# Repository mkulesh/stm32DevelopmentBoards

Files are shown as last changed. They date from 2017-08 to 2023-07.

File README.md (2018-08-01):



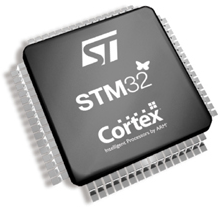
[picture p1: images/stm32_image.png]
#  "Development boards and software templates for STM32 MCU"

This repository contains schematic of development boards, PCB, and C++ source code templates that can be helpful for development using STM32 micro-controllers. It provides small, universal, and breadboards-friendly adapter and development board for wide range of STM32 controllers.  There are three sets:

## STM32-Pi Board

The first board is a two-layers STM32F4 board, which have a form-factor of Raspberry Pi B+ that allows us to use any case available for this single-board computer:

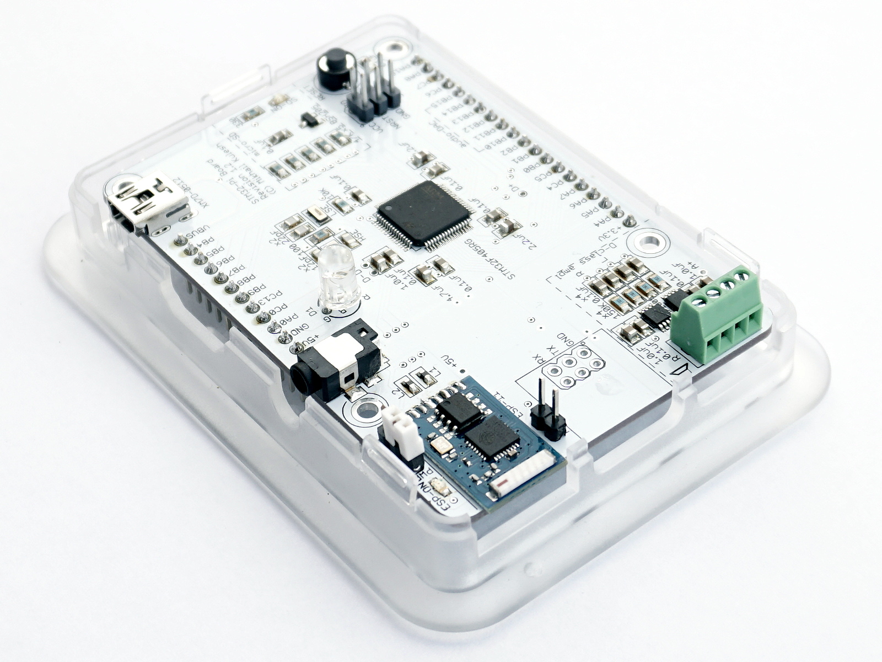
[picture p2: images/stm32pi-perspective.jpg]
Case view


If you like to test this board, you can order it [on DirtyPCBs.com](http://dirtypcbs.com/store/designer/details/9348/6105/stm32-pi-board-v1-3-zip)

### Specification
* It is based on high-performance ARM®Cortex®-M4 32-bit RISC micro-controller [STM32F405RG](http://www.st.com/en/microcontrollers/stm32f405rg.html)
* SMD HSE and LSE crystals
* Micro SD Card Connector
* Mini USB Type B Connector with USB EMI filtering and ESD protection. This connector can be used for data transfer and powering
* A separate +5V DC connector (1 mm X 3.2 mm) instead of Raspberry Pi audio jack
* 6-pin SWD connector used to program the MCU
* [ESP8266](https://en.wikipedia.org/wiki/ESP8266) WiFi Module ESP-11 instead of Raspberry Pi network connector
* 5-pin connector used to flash and program the ESP-11 module
* Breadboard-compatible 1x20-pin and 1x10-pin headers connected to free MCU pins
* Reset button
* One RGB LED
* Low power audio DAC with PLL UDA1334ATS
* 2x class-D mono audio power amplifier IS31AP2005 (2 x 2.95W) 
* 4 pads for audio output instead of Raspberry Pi USB connector
* SMD size for passive components is 0805

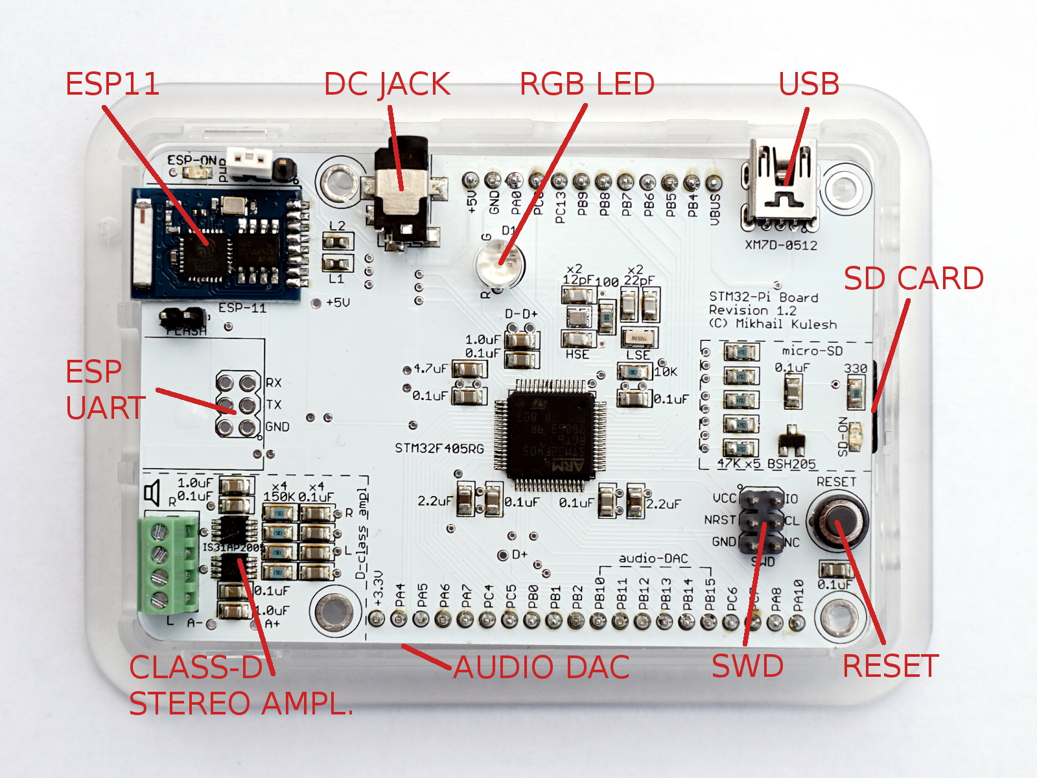
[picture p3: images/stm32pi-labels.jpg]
Top view


### Documentation
* [Отладочная плата STM32F4 в форм-факторе Raspberry Pi (In Russian)](https://habr.com/post/413101)
* [Schematic](https://docs.google.com/viewer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) 
* [Dimensions](https://docs.google.com/viewer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) 
* [Top layer](https://docs.google.com/viewer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)
* [Bottom layer](https://docs.google.com/viewer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) 
* [Bill of materials](http://htmlpreview.github.io/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)
* The C++ example in the directory [src/PI405RG](https://github.com/mkulesh/stm32DevelopmentBoards/tree/master/src/PI405RG) demonstrates how to use RTC, SD Card with FatFS, and ESP-11 module.

## Universal STM32 Boards:

These developments boards are two-side breadboard adapters for LQFP32/48/64 IC's, equipment with adaptable power supply circuit, HSE and LSE crystal circuit, reset button, and a **custom** 10-pin JTAG connector. SMD size for passive components is 0805. 

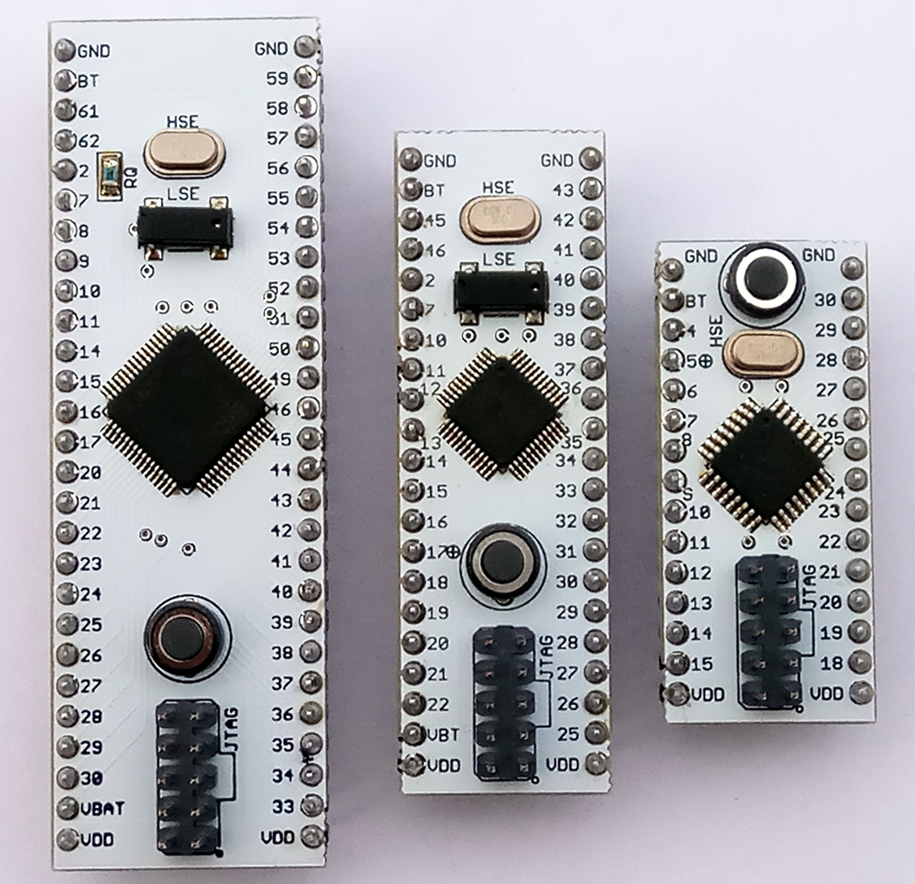
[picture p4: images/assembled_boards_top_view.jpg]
Assembled boards


The adapter between 20-pin JTAG and this custom connector is also included in the set:

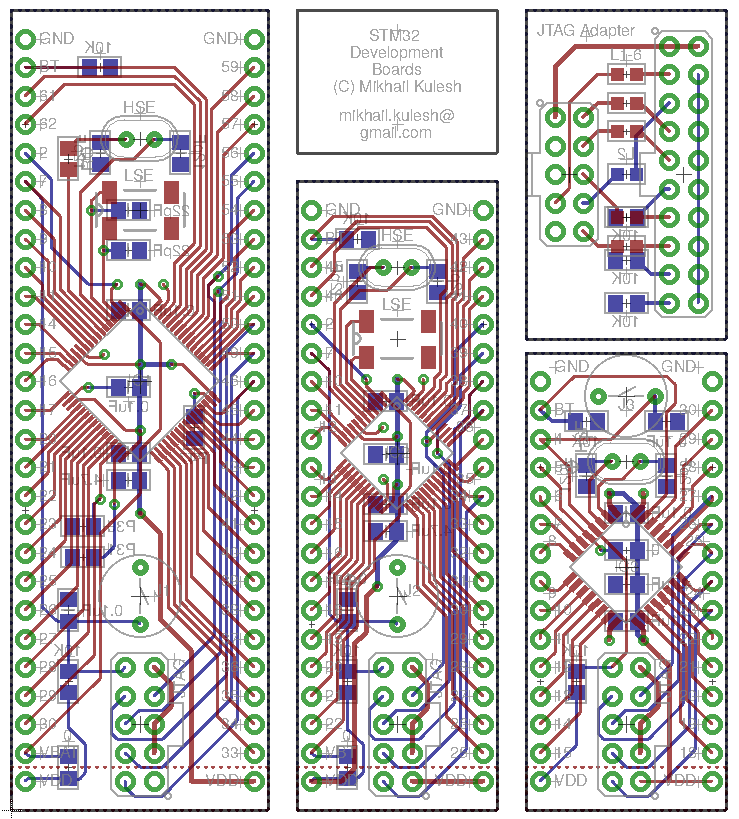
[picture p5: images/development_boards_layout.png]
Development boards layout


You can order these boards [on DirtyPCBs.com](http://dirtypcbs.com/store/designer/details/9348/5771/stm32-development-boards)

## LQFP-Breadboard Adapters:

These boards are just one-side breadboard adapters for LQFP32/48/64 IC's:

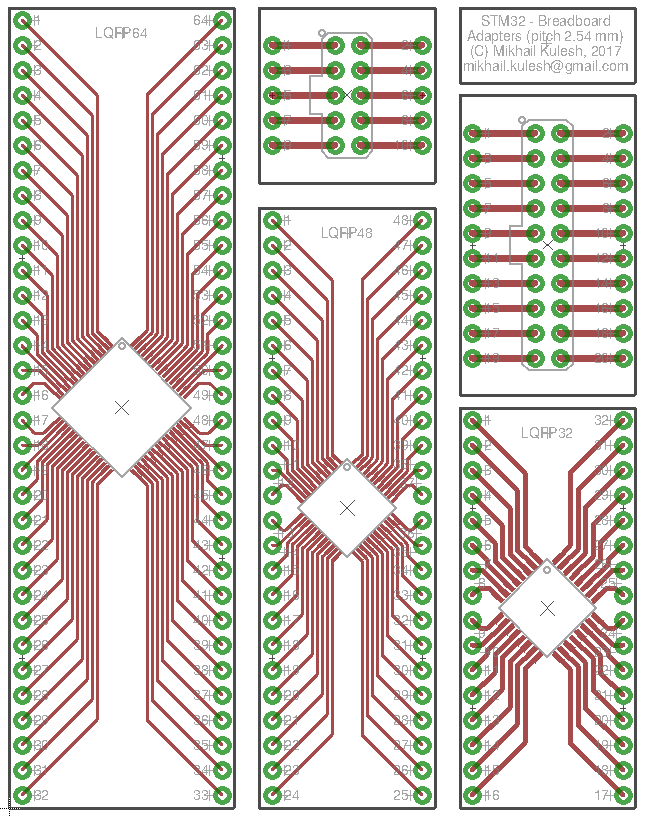
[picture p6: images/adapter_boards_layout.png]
Adapter boards layout


You can order these boards [on DirtyPCBs.com](http://dirtypcbs.com/store/designer/details/9348/5770/lqfp-adapters-zip)

## Repository Content:

* The directory **pcb** contains schematic and board layout developed in [Eagle CAD](https://www.autodesk.com/products/eagle/free-download)
* In the directory **images**, you can find some photos of assembled boards
* The directory **src** contains test examples developed in [System Workbench for STM32](http://www.st.com/en/development-tools/sw4stm32.html). These test programs are based on HAL library and an object-oriented abstraction layer called *StmPlusPlus*. Currently, following chips are tested: STM32F303K8Tx, STM32F303RBTx, STM32F373CBTx, STM32F373CCTx, STM32F410RBTx,  STM32F405RGTx

## Reviews and Publications:
* [Discussion on www.mikrocontroller.net (In German)](https://www.mikrocontroller.net/topic/433910)
* [Нестандартный способ подружиться с STM32: не Ардуино и не Discovery (In Russian)](https://habr.com/post/406313)

## License
This software is published under the *GNU General Public License, Version 3*

Copyright (C) 2014-2017 Mikhail Kulesh

This program is free software: you can redistribute it and/or modify it under the terms of the GNU General Public License as published by the Free Software Foundation, either version 3 of the License, or (at your option) any later version.

This program is distributed in the hope that it will be useful, but WITHOUT ANY WARRANTY; without even the implied warranty of MERCHANTABILITY or FITNESS FOR A PARTICULAR PURPOSE.  See the GNU General Public License for more details. You should have received a copy of the GNU General Public License along with this program.

If not, see [www.gnu.org/licenses](http://www.gnu.org/licenses).

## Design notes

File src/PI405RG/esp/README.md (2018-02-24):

# How to setup ESP-11 and flash firmware (on Linux host)

* Ensure that the [esptool](https://github.com/themadinventor/esptool) is istalled on the host PC

* Select ditectory *stm32DevelopmentBoards/src/PI405RG/esp*

* Ensure that power for STM32-Pi board is OFF

* Connect pins **1** and **2** on the **PWR** switch. Connect an USB-UART adapter to ESP pins GND/TX/RX as shown on the figure below:

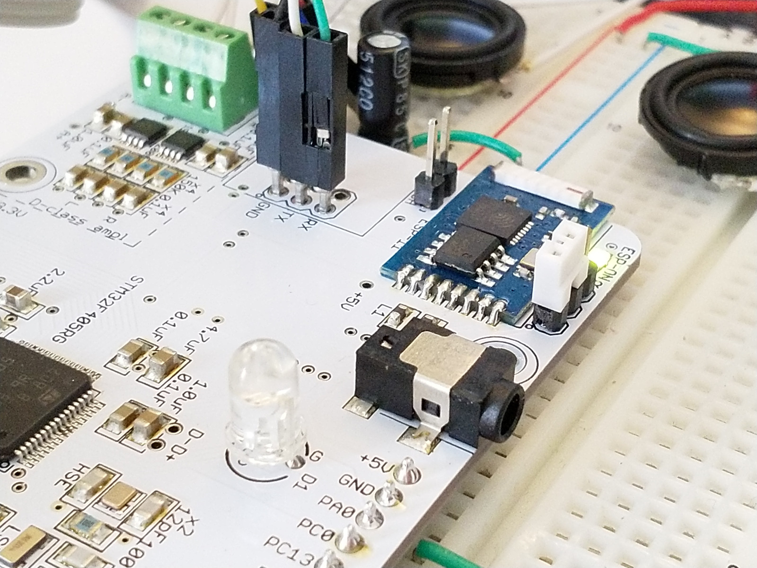
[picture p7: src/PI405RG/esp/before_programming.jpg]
Before programming


* On the host, ensure whether the USB-UART adapter is alive:
```
[stm32DevelopmentBoards/src/PI405RG/esp]# lsusb
Bus 001 Device 035: ID 0403:6001 Future Technology Devices International, Ltd FT232 Serial (UART) IC
```

* Run any terminal and connect to the ESP using following settings: baudrate **9600**, data bits **8**, parity **none**, stop bits **1**. For example, you can run CoolTerm, open there a file *CoolTermConfig.stc* and change the baudrate to **9600**.

* Switch power to ON

* In the terminal, you will see following logging:
```
[Vendor:www.ai-thinker.com Version:0.9.2.4]
ready
```

* Switch power to OFF, disconnect terminal, connect the pins **FLASH** as shown on the figure below and switch power to ON again.

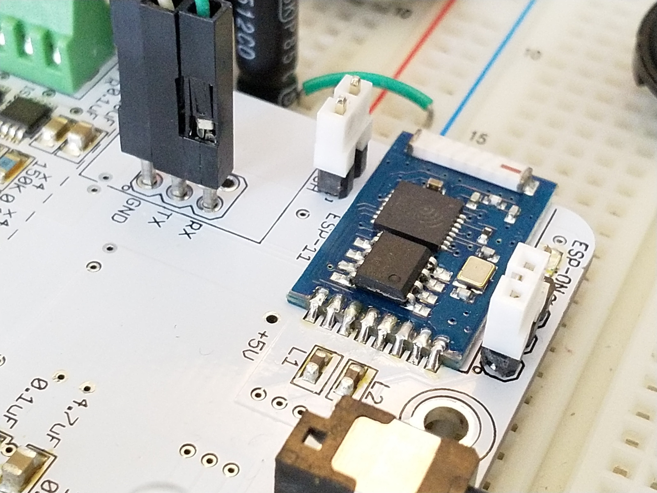
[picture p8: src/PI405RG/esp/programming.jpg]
Programming


* Adapt and run the script *flash-firmware.sh*: 
```
[stm32DevelopmentBoards/src/PI405RG/esp]# ./flash-firmware.sh 
Make sure that GPIO0 is connected to ground
esptool.py v2.2-dev
Connecting....
Detecting chip type... ESP8266
Chip is ESP8266EX
Uploading stub...
Running stub...
Stub running...
Configuring flash size...
Auto-detected Flash size: 512KB
Compressed 520192 bytes to 179836...
Wrote 520192 bytes (179836 compressed) at 0x00000000 in 16.1 seconds (effective 258.5 kbit/s)...
Hash of data verified.
Leaving...
Hard resetting...
```

* Switch power to OFF, disconnect **FLASH** pins

* In the terminal, change the baudrate to **115200**, connect to ESP and switch power to ON again. 
After ESP logs *ready*, check the actial firmware version using command *AT+GMR*:
```
AT+GMR
AT version:0.23.0.0(Apr 24 2015 21:11:01)
SDK version:1.0.1
compile time:May  9 2015 16:00:00
OK
``` 
* Connect pins **2** and **3** on the **PWR** switch. Now ESP can be accessed from MCU using USART2.

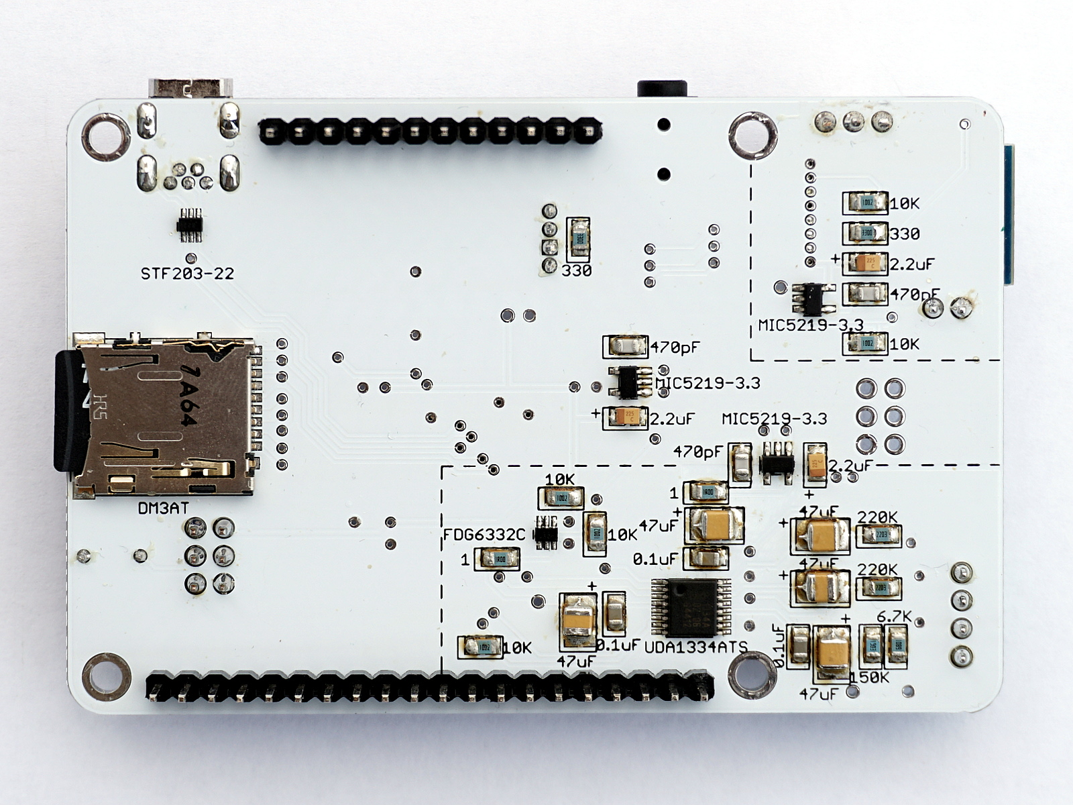
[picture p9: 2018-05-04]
images/stm32pi-bottom.jpg

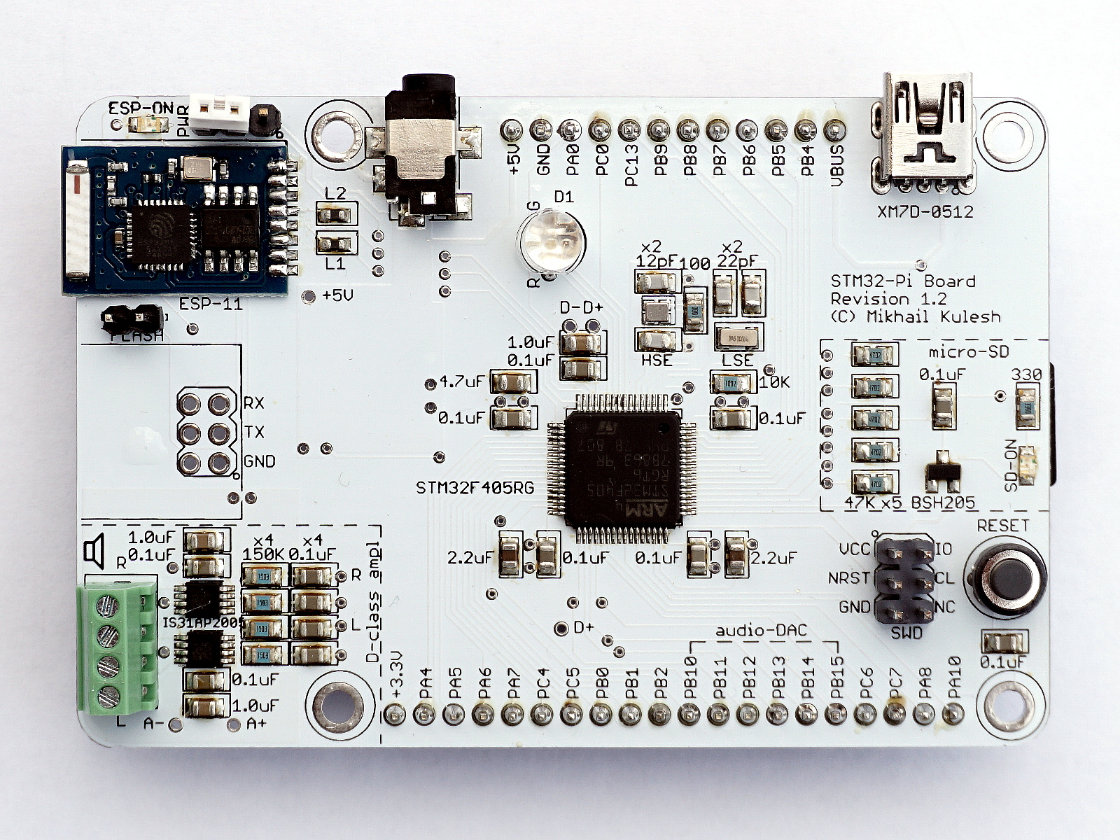
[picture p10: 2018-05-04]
images/stm32pi-top.jpg

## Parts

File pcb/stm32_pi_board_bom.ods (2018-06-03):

Qty | Value | Device | Description | MOUSER | PRICE
1 | BSH205 | BSH205G2R | P-channel enhancement mode MOSFET (-2.3A) | 771-BSH205G2R | 0,252 | 0,252
1 | BUTTON-FSM14JRT | BUTTON-FSM14JRT | TE Connectivity / Alcoswitch Round Switch | 506-1571010-1 | 0,23 | 0,23
16 | 0.1uF | C-US0805 | SMD Multilayer Ceramic Capacitor | 80-C0805C104J5RAUTO | 0,08 | 1,28
3 | 1.0uF | C-US0805 | SMD Multilayer Ceramic Capacitor | 80-C0805C104J5RAUTO | 0,1 | 0,3
2 | 12pF | C-US0805 | SMD Multilayer Ceramic Capacitor | 80-C0805C104J5RAUTO | 0,08 | 0,16
2 | 2.2uF | C-US0805 | SMD Multilayer Ceramic Capacitor | 80-C0805C104J5RAUTO | 0,1 | 0,2
2 | 22pF | C-US0805 | SMD Multilayer Ceramic Capacitor | 80-C0805C104J5RAUTO | 0,08 | 0,16
1 | 4.7uF | C-US0805 | SMD Multilayer Ceramic Capacitor | 80-C0805C104J5RAUTO | 0,1 | 0,1
3 | 470pF | C-US0805 | SMD Multilayer Ceramic Capacitor | 80-C0805C104J5RAUTO | 0,08 | 0,24
3 | 2.2uF | CPOL-US0805 | SMT Tantalum Capacitor | 581-TAJR225K016RNJ | 0,268 | 0,804
5 | 47uF | CPOL-US1311 | SMT Tantalum Capacitor | 581-F951C476KBAAQ2 | 1,34 | 6,7
1 | PJ-043-SMT | DC-POWER-JACK2 | DC Power Connector 1 mm X 3.2 mm | 490-PJ-043-SMT-TR | 0,787 | 0,787
1 | ESP-11 | ESP-11 | ESP8266 WiFi Module ESP-11 |  | 2 | 2
2 | IS31AP2005 | IS31AP2005 | Class-D mono audio power amplifier (2.95W) | 870-31AP2005SLS2TR | 0,574 | 1,148
2 | 420 Ohms | L-USL0603 | SMD Ferrite Bead | 81-BLM11B421S | 0,049 | 0,098
2 | R971 | LEDCHIP-LED0805 | LED | 604-APT2012CGCK | 0,139 | 0,278
2 | 75867-331LF | MA03-2 | Headers & Wire Housing, 2 Row, 6 Position | 649-75867-331LF | 0,623 | 1,246
2 | 68000-420HLF | MA20-1NO-PL | Headers & Wire Housing, 1 Row, 20 Position | 649-68000-420HLF | 0,656 | 1,312
3 | MIC5219-3.3 | MIC5219XX | 500mA-Peak Output LDO Regulator | 998-MIC5219-3.3YM5TR | 0,803 | 2,409
1 | DM3AT | MICRO-SD-DM3AT | DM3 Series microSD Card Connectors | 798-DM3ATSFPEJM511 | 1,95 | 1,95
1 | XM7D-0512 | MINI-USB-5-DPI | Mini USB Type B Connector | 653-XM7D-0512 | 1,56 | 1,56
1 | FDG6332C | N-P-MOS | The N & P-Channel MOSFET | 512-FDG6332C_F085 | 0,262 | 0,262
1 | 16MHz | Q-HSEFA-128 | HSE SMD Crystal | 732-FA12816F20X-AJ0 | 0,533 | 0,533
1 | 32.7680kHz | Q-LSECM7V-T1A | 32.768 kHz SMD Crystal | 428-201562-MG01 | 0,418 | 0,418
2 | 1 | R-US0805 | SMD Resistor | 660-RK73H2ATTDD1R00F | 0,02 | 0,04
1 | 100 | R-US0805 | SMD Resistor | 660-RK73H2ATTDD1R00F | 0,02 | 0,02
3 | 330 | R-US0805 | SMD Resistor | 660-RK73H2ATTDD1R00F | 0,02 | 0,06
6 | 10K | R-US0805 | SMD Resistor | 660-RK73H2ATTDD1R00F | 0,02 | 0,12
5 | 150K | R-US0805 | SMD Resistor | 660-RK73H2ATTDD1R00F | 0,02 | 0,1
2 | 220K | R-US0805 | SMD Resistor | 660-RK73H2ATTDD1R00F | 0,02 | 0,04
5 | 47K | R-US0805 | SMD Resistor | 660-RK73H2ATTDD1R00F | 0,02 | 0,1
1 | 6.7K | R-US0805 | SMD Resistor | 660-RK73H2ATTDD1R00F | 0,02 | 0,02
1 | WP154A4SUREQBFZGC | RGB-LED-5MM | T-1 3/4 (5mm) full color LED lamp | 604-WP154A4SUREQBFZG | 1,55 | 1,55
1 | STF203-22 | STF203-22 | USB EMI filtering and ESD protection | 947-STF203-22.TCT | 0,746 | 0,746
1 | STM32F405RG | STM32F405RGT | ARM 32-bit Cortexâ„¢-M3 CPU | 511-STM32F405RGT6 | 8,68 | 8,68
1 | UDA1334ATS | UDA1334ATS | Low power audio DAC with PLL | 771-UDA1334ATSDH-T | 1,17 | 1,17
 |  |  |  |  |  | 37,073

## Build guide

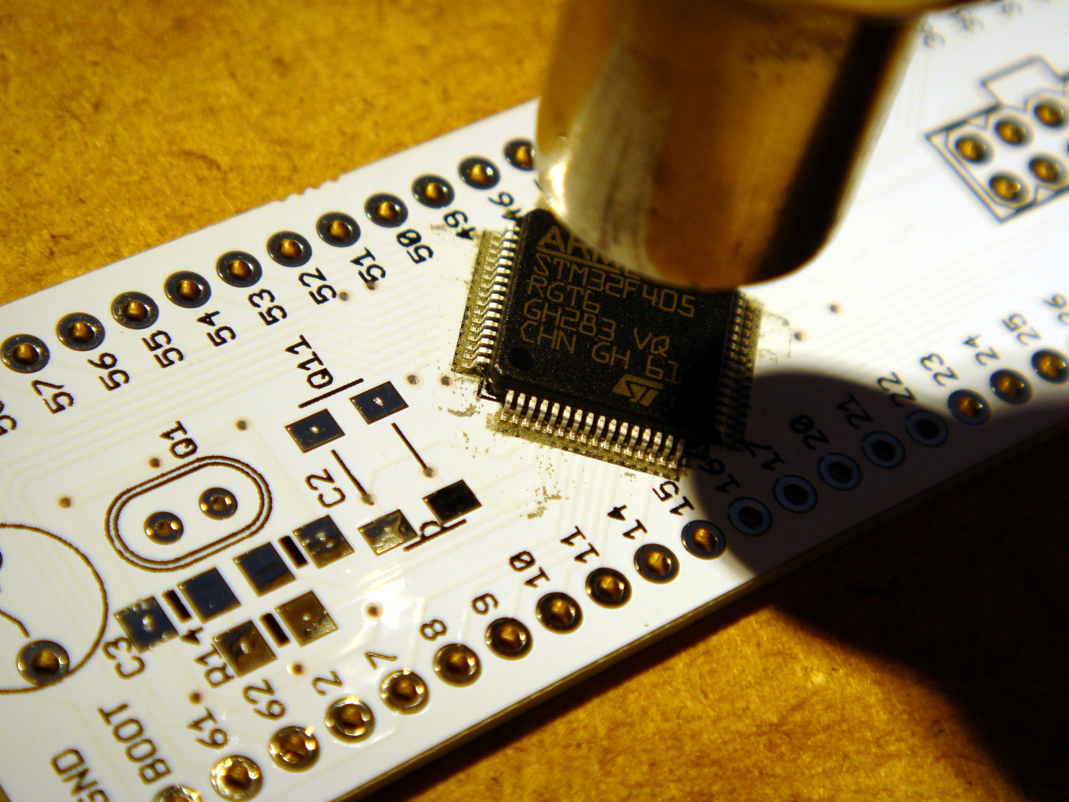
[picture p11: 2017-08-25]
images/howToAssemble/assemble06.jpg

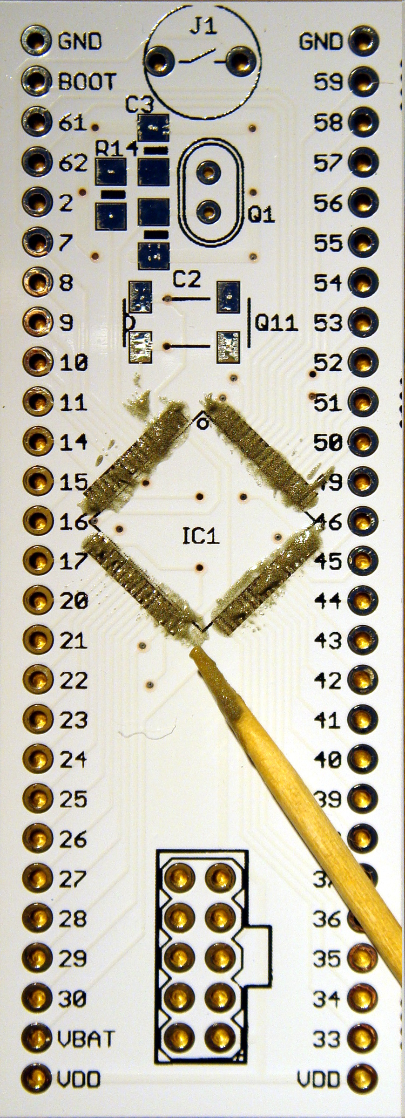
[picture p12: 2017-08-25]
images/howToAssemble/assemble02.jpg

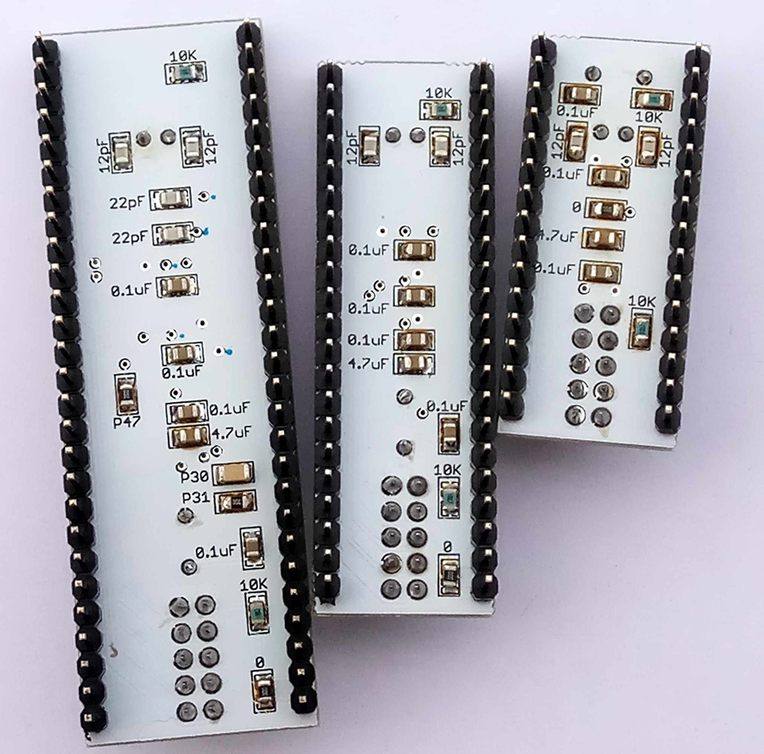
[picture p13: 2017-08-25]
images/assembled_boards_bottom_view.jpg

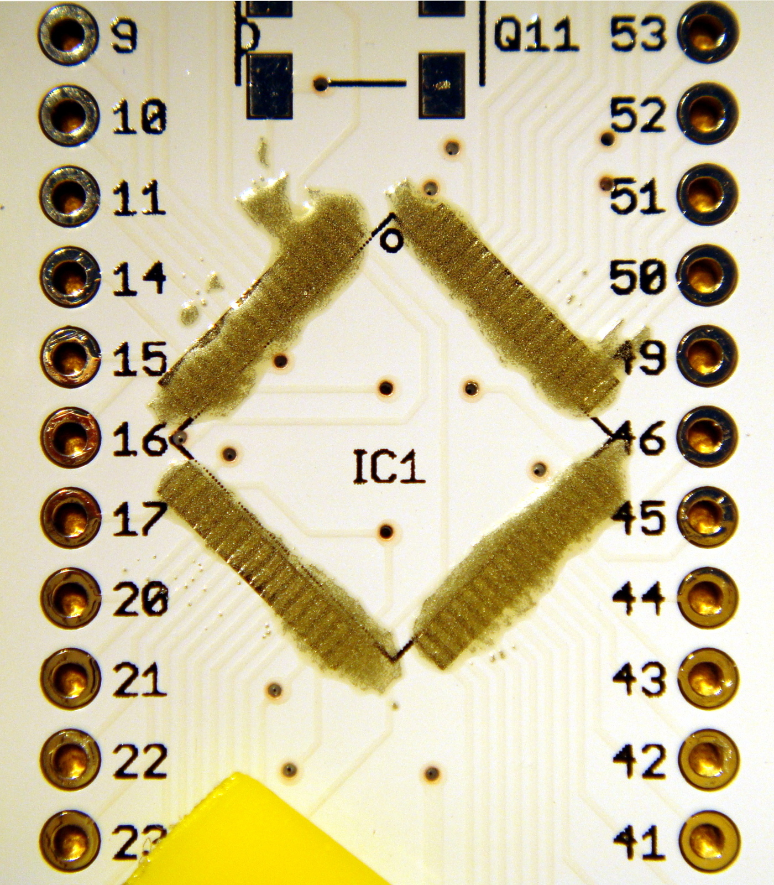
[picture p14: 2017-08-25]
images/howToAssemble/assemble03.jpg

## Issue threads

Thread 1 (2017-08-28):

Replace JTAG by SWD and add SWD pin's labels

mkulesh, 2017-08-28:

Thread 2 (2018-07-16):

Stm32F103C8T6 and stm32DevelopmentBoards

NickNifontov, 2018-07-16:
Отличный проект.

Хочу попробовать собрать Universal STM32 Boards вместе с Stm32F103C8T6.

Был ли опыт сбора с этим камнем?

Хочу попробовать совместить на одной board'е сразу и USB  и питание RAW (AMS1117)

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

или идея того не стоит?

NickNifontov, 2018-07-16:
Если есть доступными eagle файлы - выложите .

Заранее спасибо

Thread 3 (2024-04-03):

Not really an issue

abelykh0, 2024-04-03:
Please mention a similar great resource https://stm32-base.org/boards/ (I am not affiliated either with them or STM32)

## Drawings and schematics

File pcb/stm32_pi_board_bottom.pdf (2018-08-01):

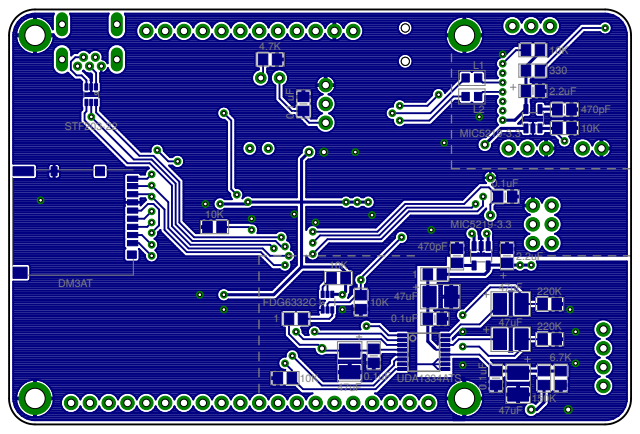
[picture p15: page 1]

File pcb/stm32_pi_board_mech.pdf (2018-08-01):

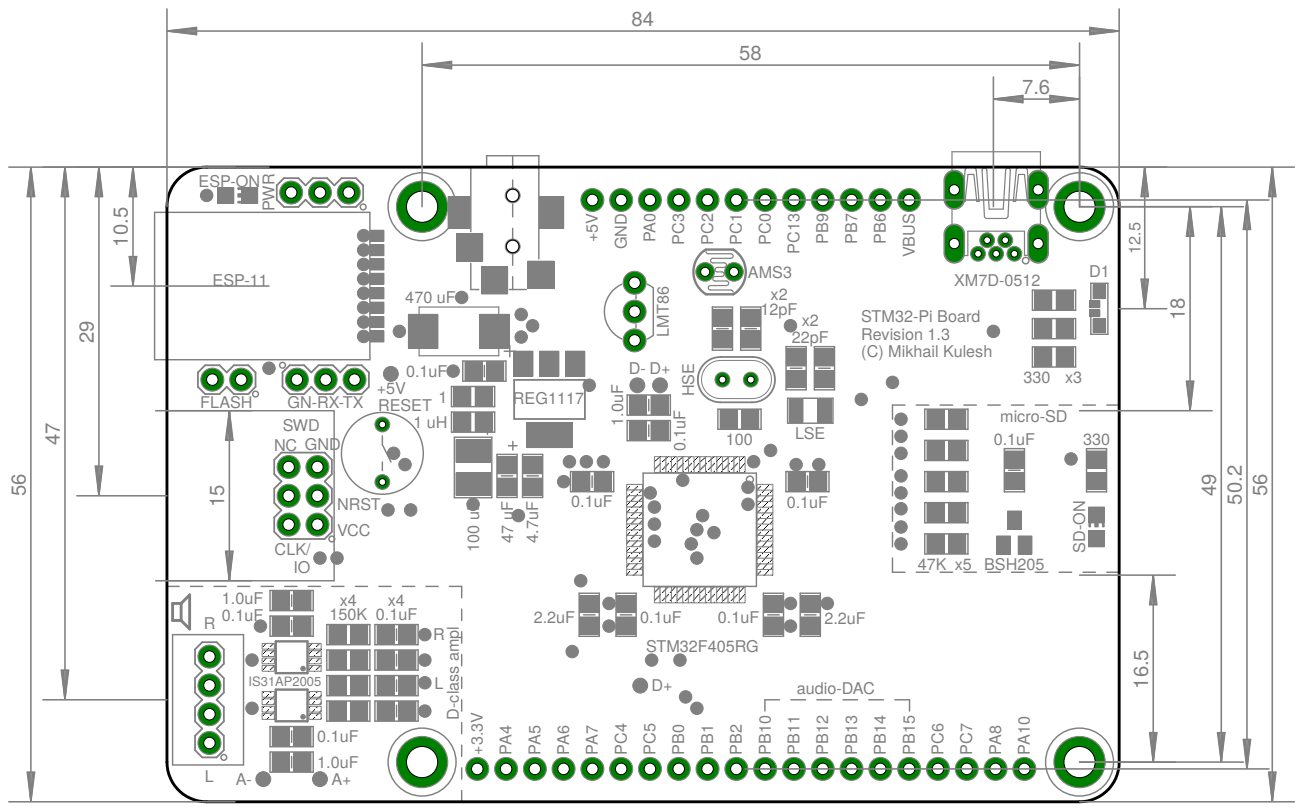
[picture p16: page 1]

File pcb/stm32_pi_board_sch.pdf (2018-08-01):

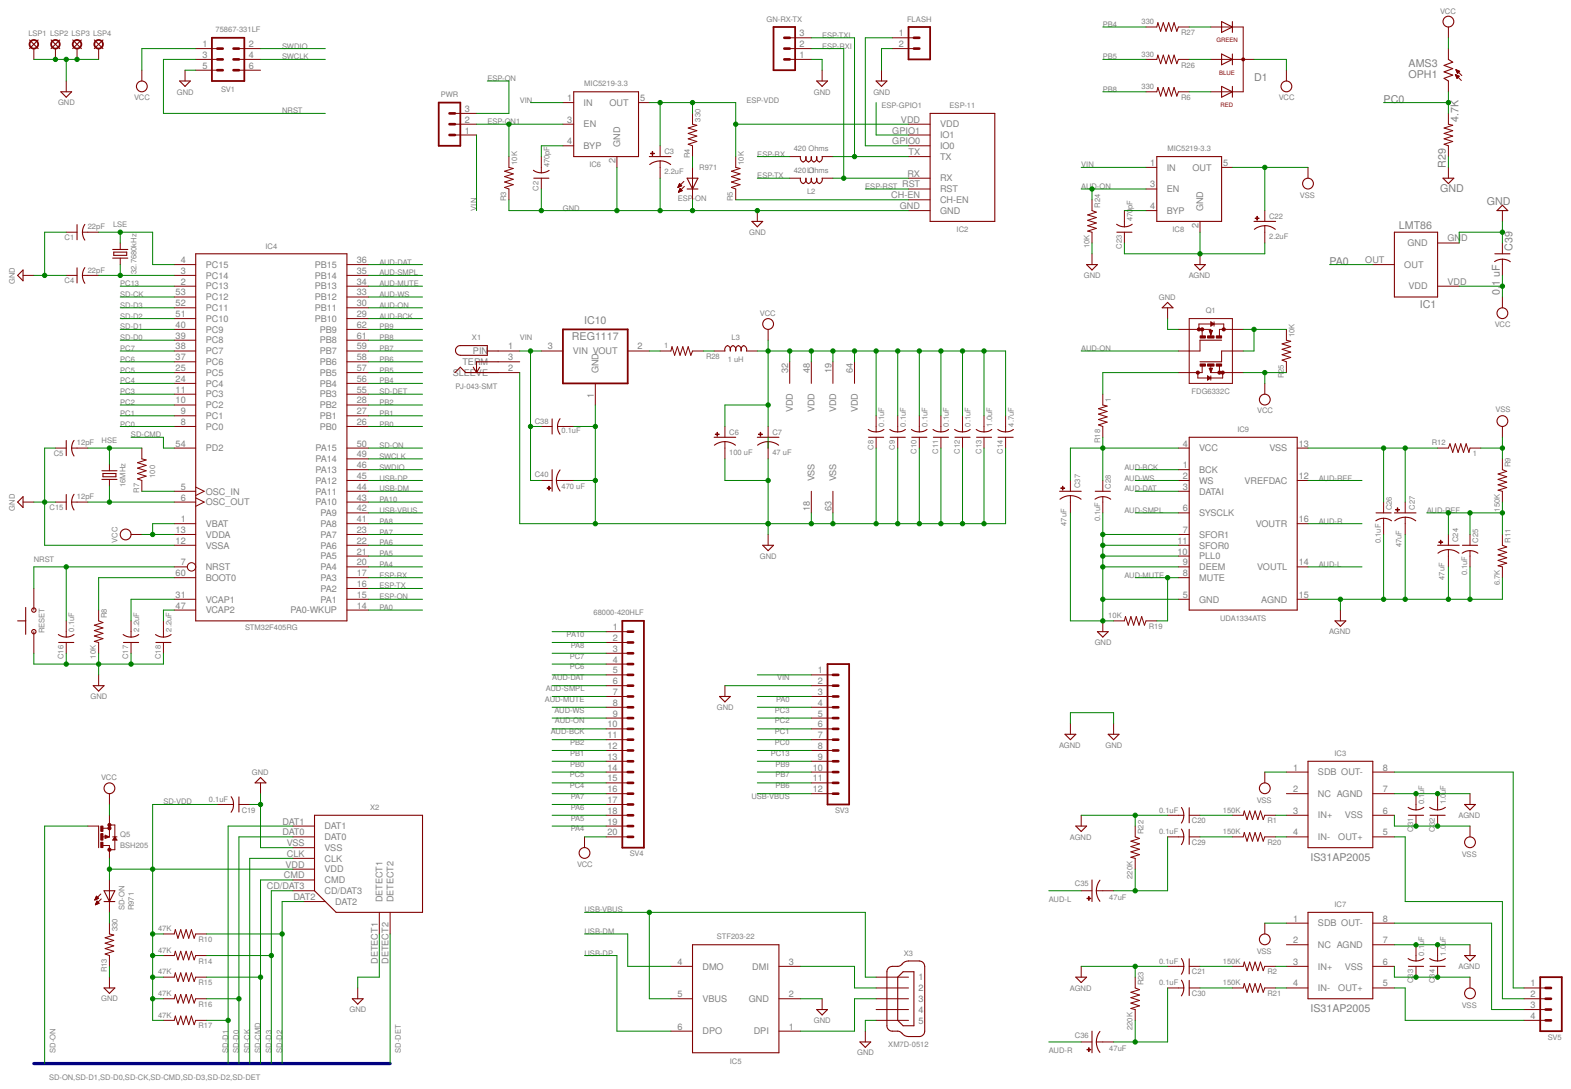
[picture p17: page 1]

ESP-RXI ESP-TXI

SD-DET SD-DET PC0

AUD-REF

SD-ON,SD-D1,SD-D0,SD-CK,SD-CMD,SD-D3,SD-D2,SD-DET

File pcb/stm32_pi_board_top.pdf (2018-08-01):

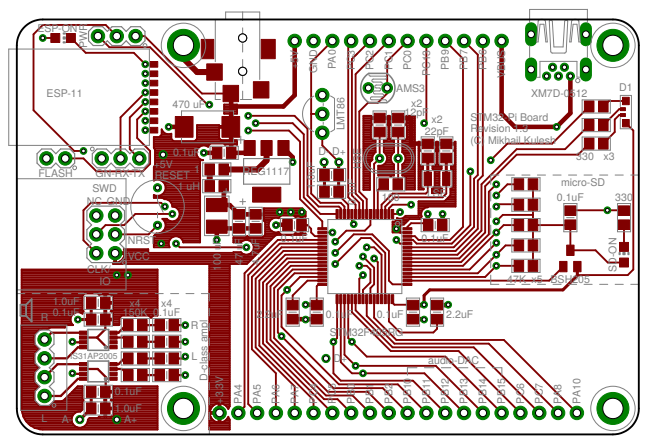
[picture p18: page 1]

1.0uF
0.1uF | | 150K 0.1uF

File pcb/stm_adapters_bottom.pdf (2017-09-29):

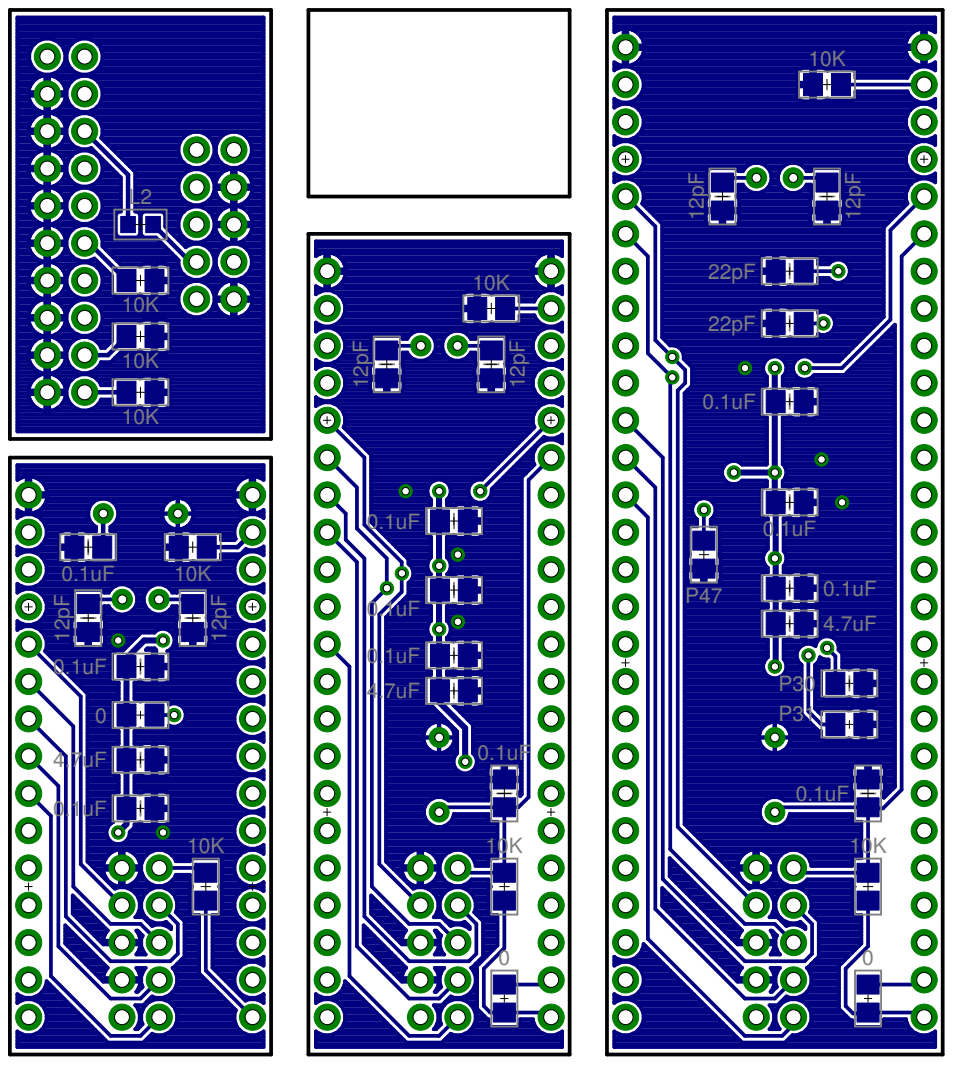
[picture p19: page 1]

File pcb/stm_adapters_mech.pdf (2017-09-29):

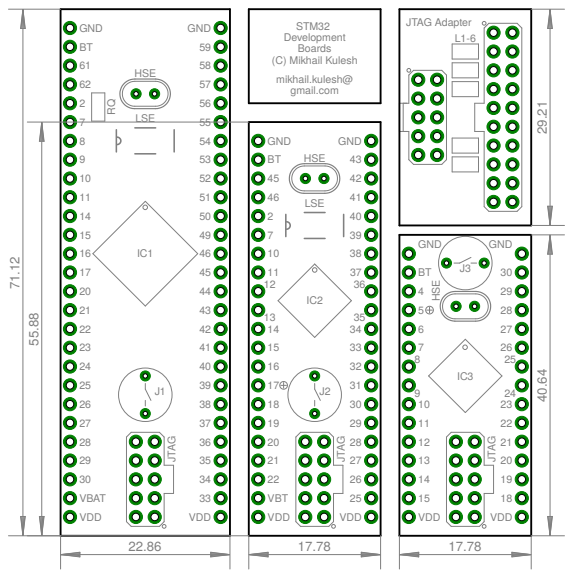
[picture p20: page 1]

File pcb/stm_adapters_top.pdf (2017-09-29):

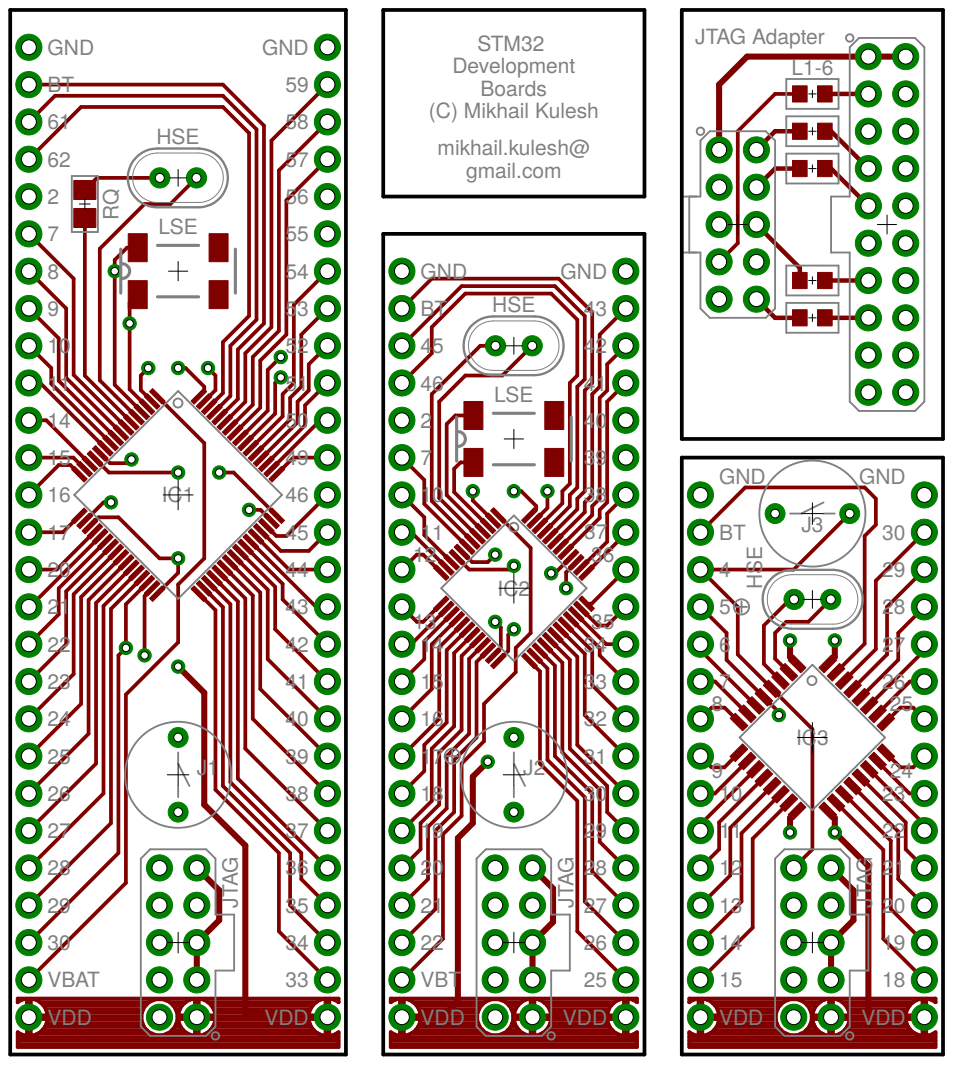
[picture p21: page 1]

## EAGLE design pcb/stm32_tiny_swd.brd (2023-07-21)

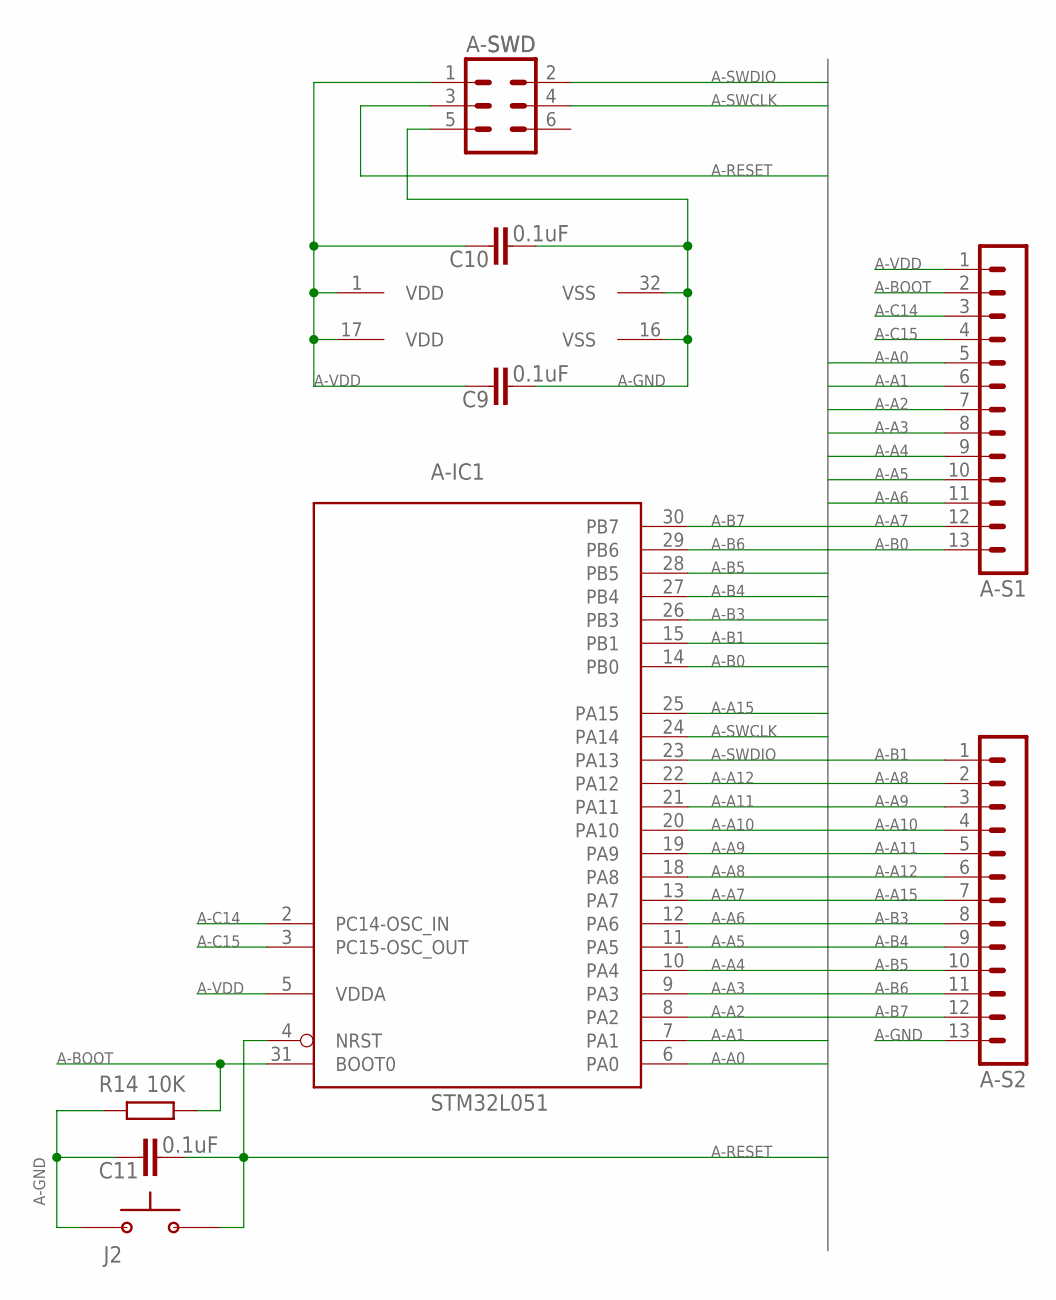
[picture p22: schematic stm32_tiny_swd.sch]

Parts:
A-IC1: STM32L051; LQFP32
A-S1, A-S2: MA13-1
A-SWD: SWD; MA03-2
C9, C10, C11: 0.1uF; C0805
J2: BUTTON-FSM14JRT
R14: 10K; R0805

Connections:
A-A0: A-IC1.6 (PA0), A-S1.5
A-A1: A-IC1.7 (PA1), A-S1.6
A-A2: A-IC1.8 (PA2), A-S1.7
A-A3: A-IC1.9 (PA3), A-S1.8
A-A4: A-IC1.10 (PA4), A-S1.9
A-A5: A-IC1.11 (PA5), A-S1.10
A-A6: A-IC1.12 (PA6), A-S1.11
A-A7: A-IC1.13 (PA7), A-S1.12
A-A8: A-IC1.18 (PA8), A-S2.2
A-A9: A-IC1.19 (PA9), A-S2.3
A-A10: A-IC1.20 (PA10), A-S2.4
A-A11: A-IC1.21 (PA11), A-S2.5
A-A12: A-IC1.22 (PA12), A-S2.6
A-A15: A-IC1.25 (PA15), A-S2.7
A-B0: A-IC1.14 (PB0), A-S1.13
A-B1: A-IC1.15 (PB1), A-S2.1
A-B3: A-IC1.26 (PB3), A-S2.8
A-B4: A-IC1.27 (PB4), A-S2.9
A-B5: A-IC1.28 (PB5), A-S2.10
A-B6: A-IC1.29 (PB6), A-S2.11
A-B7: A-IC1.30 (PB7), A-S2.12
A-BOOT: A-IC1.31 (BOOT0), A-S1.2, R14.1
A-C14: A-IC1.2 (PC14-OSC_IN), A-S1.3
A-C15: A-IC1.3 (PC15-OSC_OUT), A-S1.4
A-GND: A-IC1.16 (VSS), A-IC1.32 (VSS), A-S2.13, A-SWD.5, C9.2, C10.2, C11.1, J2.P$1 (1), R14.2
A-RESET: A-IC1.4 (NRST), A-SWD.3, C11.2, J2.P$2 (2)
A-SWCLK: A-IC1.24 (PA14), A-SWD.4
A-SWDIO: A-IC1.23 (PA13), A-SWD.2
A-VDD: A-IC1.1 (VDD), A-IC1.5 (VDDA), A-IC1.17 (VDD), A-S1.1, A-SWD.1, C9.1, C10.1

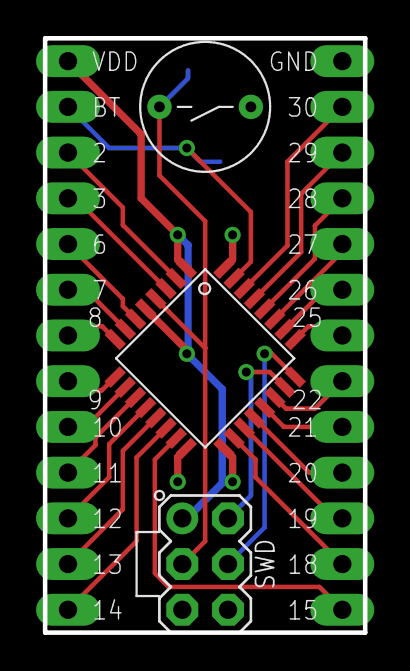
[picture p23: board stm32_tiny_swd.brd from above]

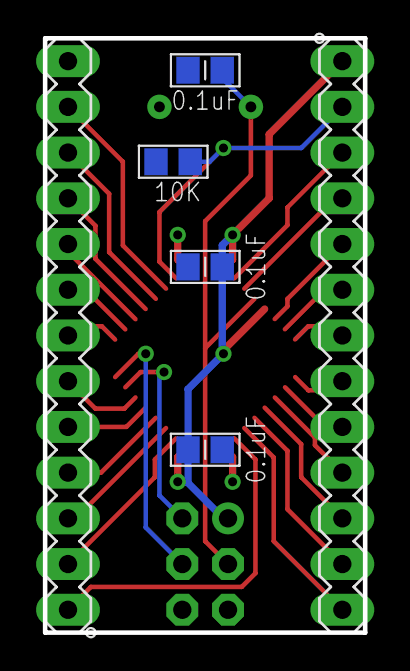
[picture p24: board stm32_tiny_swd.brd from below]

Board: 2 copper layers, 17.8 x 33.0 mm, 9 parts (6 on the bottom side), 29 nets.

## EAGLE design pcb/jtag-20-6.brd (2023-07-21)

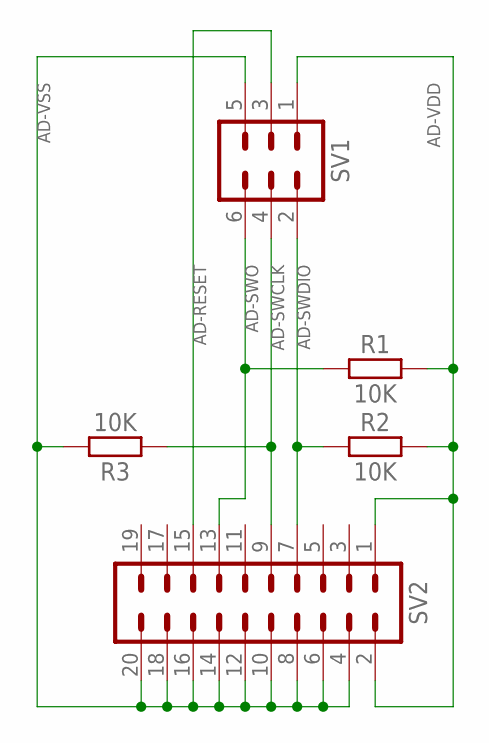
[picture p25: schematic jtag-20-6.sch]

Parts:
R1, R2, R3: 10K; R1206
SV1: MA03-2
SV2: MA10-2

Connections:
AD-RESET: SV1.3, SV2.15
AD-SWCLK: R3.1, SV1.4, SV2.9
AD-SWDIO: R2.1, SV1.2, SV2.7
AD-SWO: R1.1, SV1.6, SV2.13
AD-VDD: R1.2, R2.2, SV1.1, SV2.1, SV2.2
AD-VSS: R3.2, SV1.5, SV2.4, SV2.6, SV2.8, SV2.10, SV2.12, SV2.14, SV2.16, SV2.18, SV2.20

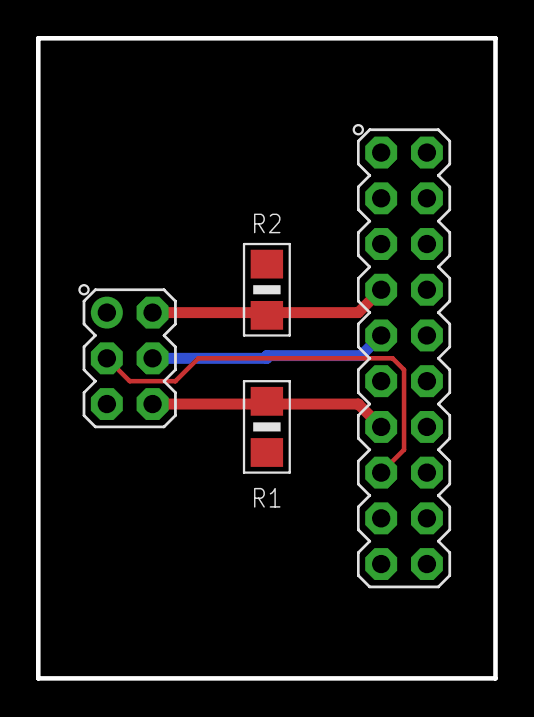
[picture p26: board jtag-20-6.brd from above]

Board: 2 copper layers, 25.4 x 35.6 mm, 5 parts (1 on the bottom side), 6 nets.

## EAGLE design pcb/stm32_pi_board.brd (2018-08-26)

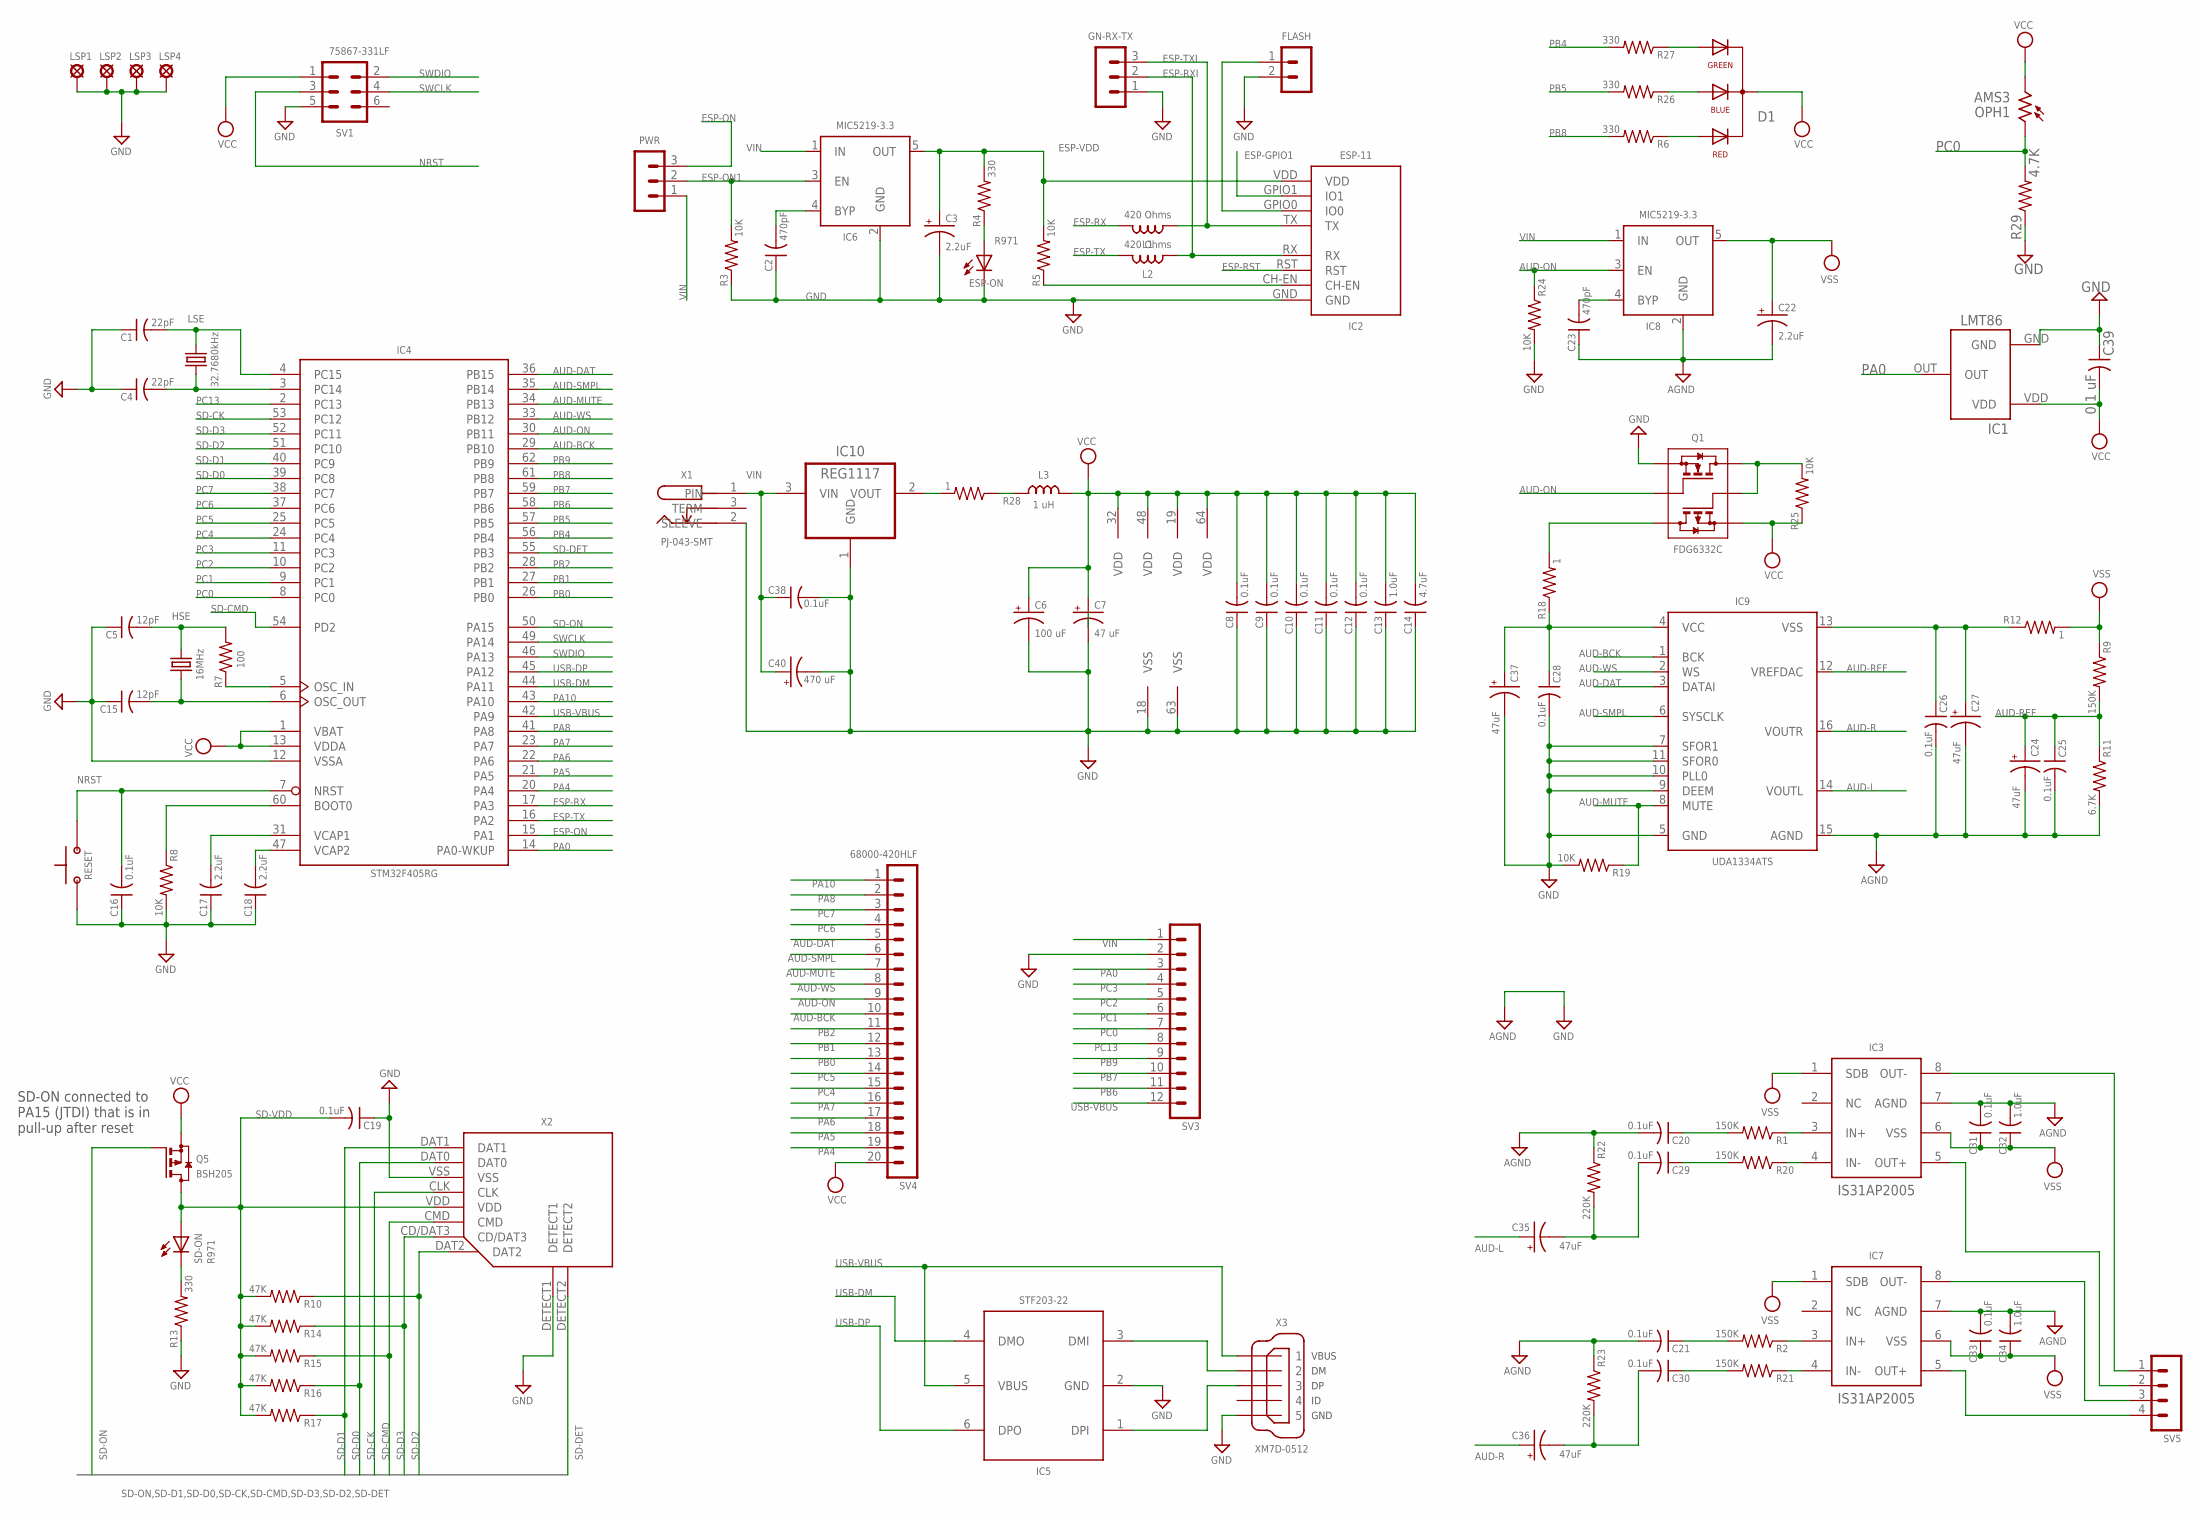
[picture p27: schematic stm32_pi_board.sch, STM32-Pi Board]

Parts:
C1, C4: 22pF; C0805
C2, C23: 470pF; C0805
C3, C22: 2.2uF; CPOL0805
C5, C15: 12pF; C0805
C6: 100 uF; CPOL1311
C7: 47 uF; CPOL0805
C8, C9, C10, C11, C12, C16, C19, C20, C21, C25, C26, C28, C29, C30, C31, C33, C38: 0.1uF; C0805
C13, C32, C34: 1.0uF; C0805
C14: 4.7uF; C0805
C17, C18: 2.2uF; C0805
C24, C27, C35, C36, C37: 47uF; CPOL1311
C39: 0.1 uF; C0805
C40: 470 uF; CPOL2917
D1: RGB-LED3X1MM; RGB-LED-SMD-3X1
ESP-ON: R971; CHIP-LED0805
FLASH: MA02-1
GN-RX-TX: MA03-1PL; MA03-1
HSE: 16MHz; Q-HC-46X
IC1: LMT86
IC2: ESP-11
IC3, IC7: IS31AP2005; MSOP-8
IC4: STM32F405RG; LQFP64
IC5: STF203-22; SC70-6
IC6, IC8: MIC5219-3.3; SOT23-5
IC9: UDA1334ATS; SSOP16
IC10: REG1117; SOT223
L1, L2: 420 Ohms; L0603
L3: 1 uH; L0805
LSE: 32.7680kHz; Q-CM7V-T1A
LSP1, LSP2, LSP3, LSP4: LSP27
OPH1: AMS3; VT900
PWR: MA03-1PL; MA03-1
Q1: FDG6332C; SC70-6
Q5: BSH205; SOT23
R1, R2, R9, R20, R21: 150K; R0805
R3, R5, R8, R19, R24, R25: 10K; R0805
R4, R6, R13, R26, R27: 330; R0805
R7: 100; R0805
R10, R14, R15, R16, R17: 47K; R0805
R11: 6.7K; R0805
R12, R18, R28: 1; R0805
R22, R23: 220K; R0805
R29: 4.7K; R0805
RESET: BUTTON-FSM14JRT
SD-ON: R971; CHIP-LED0805
SV1: 75867-331LF; MA03-2
SV3: MA12-1NO-PL; MA12-1-NO-PL
SV4: 68000-420HLF; MA20-1-NO-PL
SV5: MA04-1PL; MA04-1
X1: PJ-043-SMT; BUCHSE-1.0X3.2
X2: DM3AT
X3: XM7D-0512

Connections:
AUD-BCK: IC4.29 (PB10), IC9.1 (BCK), SV4.10
AUD-DAT: IC4.36 (PB15), IC9.3 (DATAI), SV4.5
AUD-L: C35.1+ (+), IC9.14 (VOUTL)
AUD-MUTE: IC4.34 (PB13), IC9.8 (MUTE), R19.1, SV4.7
AUD-ON: IC4.30 (PB11), IC8.3 (EN), Q1.2, R24.1, SV4.9
AUD-R: C36.1+ (+), IC9.16 (VOUTR)
AUD-REF: C24.1+ (+), C25.1, IC9.12 (VREFDAC), R9.2, R11.1
AUD-SMPL: IC4.35 (PB14), IC9.6 (SYSCLK), SV4.6
AUD-WS: IC4.33 (PB12), IC9.2 (WS), SV4.8
BOOT: IC4.60 (BOOT0), R8.1
ESP-GPIO1: IC2.GPIO1 (IO1)
ESP-IO0: FLASH.1, IC2.GPIO0 (IO0)
ESP-ON: IC4.15 (PA1), PWR.3
ESP-ON1: IC6.3 (EN), PWR.2, R3.2
ESP-RST: IC2.RST
ESP-RX: IC4.17 (PA3), L1.2
ESP-RXI: GN-RX-TX.2, IC2.RX, L2.1
ESP-TX: IC4.16 (PA2), L2.2
ESP-TXI: GN-RX-TX.3, IC2.TX, L1.1
ESP-VDD: C3.1+ (+), IC2.VDD, IC6.5 (OUT), R4.2, R5.2
GND: C1.1, C2.1, C3.2- (-), C4.1, C5.1, C6.2- (-), C7.2- (-), C8.1, C9.1, C10.1, C11.1, C12.1, C13.1, C14.1, C15.1, C16.1, C17.1, C18.1, C19.1, C20.2, C21.2, C22.2- (-), C23.1, C24.2- (-), C25.2, C26.2, C27.2- (-), C28.2, C31.2, C32.2, C33.2, C34.2, C37.2- (-), C38.2, C39.1, C40.-, ESP-ON.C, FLASH.2, GN-RX-TX.1, IC1.GND, IC2.GND, IC3.7 (AGND), IC4.12 (VSSA), IC4.18 (VSS), IC4.63 (VSS), IC5.2 (GND), IC6.2 (GND), IC7.7 (AGND), IC8.2 (GND), IC9.5 (GND), IC9.7 (SFOR1), IC9.9 (DEEM), IC9.10 (PLL0), IC9.11 (SFOR0), IC9.15 (AGND), IC10.1 (GND), LSP1.MP, LSP2.MP, LSP3.MP, LSP4.MP, Q1.1, R3.1, R8.2, R11.2, R13.1, R19.2, R22.1, R23.1, R24.2, R29.1, RESET.P$1 (1), SV1.5, SV3.2, X1.2 (SLEEVE), X2.DETECT1, X2.VSS, X3.5
unnamed: C2.2, IC6.4 (BYP)
unnamed: D1.P$1 (AR), R6.1
unnamed: IC4.5 (OSC_IN), R7.1
unnamed: ESP-ON.A, R4.1
unnamed: IC3.8 (OUT-), SV5.1
unnamed: IC3.5 (OUT+), SV5.2
unnamed: C20.1, R1.2
unnamed: IC7.8 (OUT-), SV5.3
unnamed: IC7.5 (OUT+), SV5.4
unnamed: IC3.3 (IN+), R1.1
unnamed: IC7.3 (IN+), R2.1
unnamed: IC5.1 (DPI), X3.3
unnamed: IC5.3 (DMI), X3.2
unnamed: C21.1, R2.2
unnamed: IC3.4 (IN-), R20.1
unnamed: D1.P$4 (AB), R26.1
unnamed: C28.1, C37.1+ (+), IC9.4 (VCC), R18.1
unnamed: IC7.4 (IN-), R21.1
unnamed: C23.2, IC8.4 (BYP)
unnamed: C26.1, C27.1+ (+), IC9.13 (VSS), R12.1
unnamed: C30.1, R21.2
unnamed: IC2.CH-EN, R5.1
unnamed: C29.1, R20.2
unnamed: C29.2, C35.2- (-), R22.2
unnamed: Q1.3, R18.2
unnamed: C5.2, HSE.1, R7.2
unnamed: C30.2, C36.2- (-), R23.2
unnamed: D1.P$3 (AG), R27.1
unnamed: C15.2, HSE.2, IC4.6 (OSC_OUT)
unnamed: IC10.2 (VOUT), R28.2
unnamed: Q1.5, Q1.6, R25.2
unnamed: L3.1, R28.1
unnamed: R13.2, SD-ON.C
NRST: C16.2, IC4.7 (NRST), RESET.P$2 (2), SV1.3
PA0: IC1.OUT, IC4.14 (PA0-WKUP), SV3.3
PA4: IC4.20 (PA4), SV4.19
PA5: IC4.21 (PA5), SV4.18
PA6: IC4.22 (PA6), SV4.17
PA7: IC4.23 (PA7), SV4.16
PA8: IC4.41 (PA8), SV4.2
PA10: IC4.43 (PA10), SV4.1
PB0: IC4.26 (PB0), SV4.13
PB1: IC4.27 (PB1), SV4.12
PB2: IC4.28 (PB2), SV4.11
PB4: IC4.56 (PB4), R27.2
PB5: IC4.57 (PB5), R26.2
PB6: IC4.58 (PB6), SV3.11
PB7: IC4.59 (PB7), SV3.10
PB8: IC4.61 (PB8), R6.2
PB9: IC4.62 (PB9), SV3.9
PC0: IC4.8 (PC0), OPH1.1, R29.2, SV3.7
PC1: IC4.9 (PC1), SV3.6
PC2: IC4.10 (PC2), SV3.5
PC3: IC4.11 (PC3), SV3.4
PC4: IC4.24 (PC4), SV4.15
PC5: IC4.25 (PC5), SV4.14
PC6: IC4.37 (PC6), SV4.4
PC7: IC4.38 (PC7), SV4.3
PC13: IC4.2 (PC13), SV3.8
Q2M: C4.2, IC4.3 (PC14), LSE.1
Q2P: C1.2, IC4.4 (PC15), LSE.2
SD-CK: IC4.53 (PC12), X2.CLK
SD-CMD: IC4.54 (PD2), R15.1, X2.CMD
SD-D0: IC4.39 (PC8), R16.1, X2.DAT0
SD-D1: IC4.40 (PC9), R17.1, X2.DAT1
SD-D2: IC4.51 (PC10), R10.1, X2.DAT2
SD-D3: IC4.52 (PC11), R14.1, X2.CD/DAT3
SD-DET: IC4.55 (PB3), X2.DETECT2
SD-ON: IC4.50 (PA15), Q5.1 (G)
SD-VDD: C19.2, Q5.3 (D), R10.2, R14.2, R15.2, R16.2, R17.2, SD-ON.A, X2.VDD
SWCLK: IC4.49 (PA14), SV1.4
SWDIO: IC4.46 (PA13), SV1.2
USB-DM: IC4.44 (PA11), IC5.4 (DMO)
USB-DP: IC4.45 (PA12), IC5.6 (DPO)
USB-VBUS: IC4.42 (PA9), IC5.5 (VBUS), SV3.12, X3.1
VCAP3: C18.2, IC4.47 (VCAP2)
VCAP4: C17.2, IC4.31 (VCAP1)
VDD: C6.1+ (+), C7.1+ (+), C8.2, C9.2, C10.2, C11.2, C12.2, C13.2, C14.2, C39.2, D1.P$2 (C), IC1.VDD, IC4.1 (VBAT), IC4.13 (VDDA), IC4.19 (VDD), IC4.32 (VDD), IC4.48 (VDD), IC4.64 (VDD), L3.2, OPH1.2, Q1.4, Q5.2 (S), R25.1, SV1.1, SV4.20
VIN: C38.1, C40.+, IC6.1 (IN), IC8.1 (IN), IC10.3 (VIN), PWR.1, SV3.1, X1.1 (PIN)
VSS: C22.1+ (+), C31.1, C32.1, C33.1, C34.1, IC3.1 (SDB), IC3.6 (VSS), IC7.1 (SDB), IC7.6 (VSS), IC8.5 (OUT), R9.1, R12.2

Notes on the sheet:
SD-ON connected to PA15 (JTDI) that is in pull-up after reset

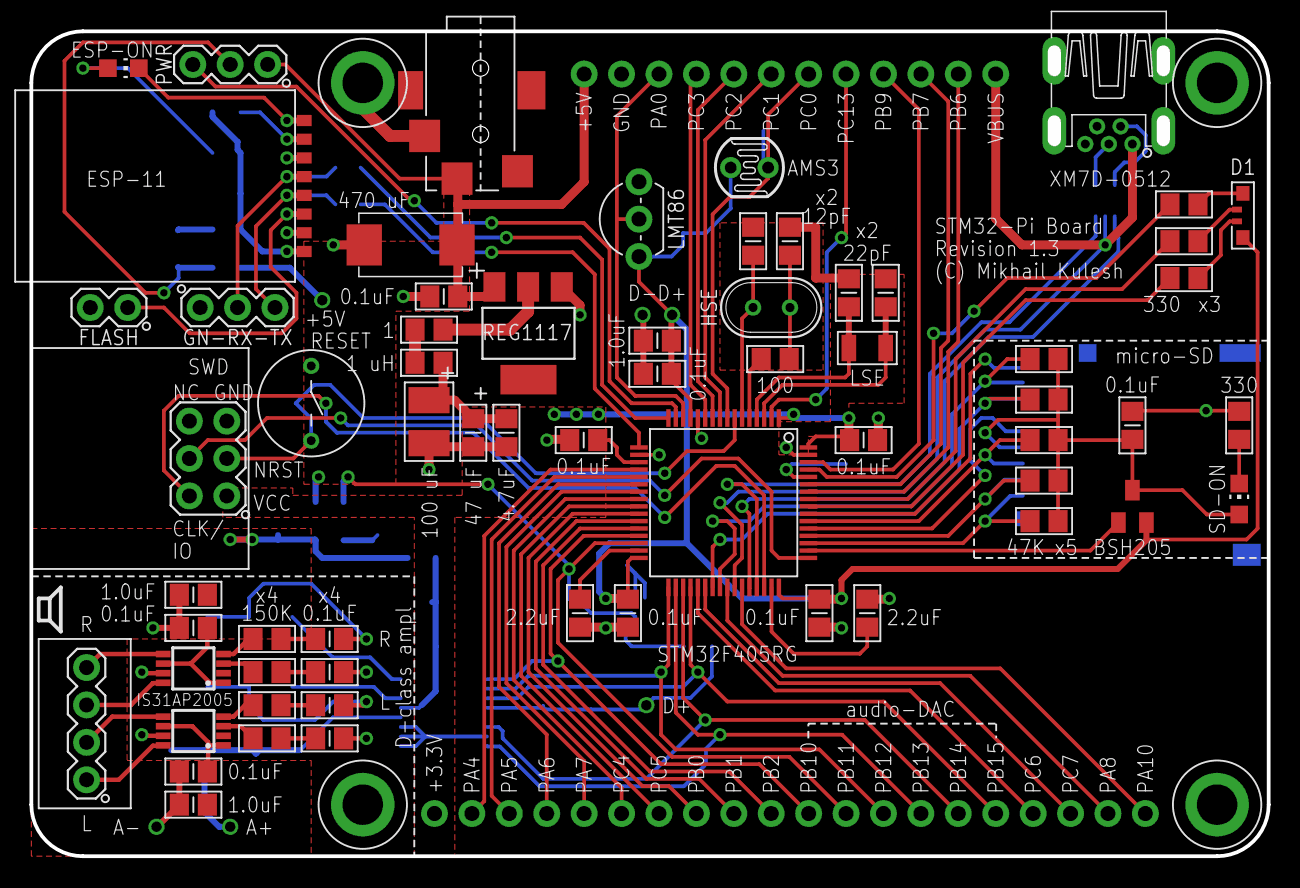
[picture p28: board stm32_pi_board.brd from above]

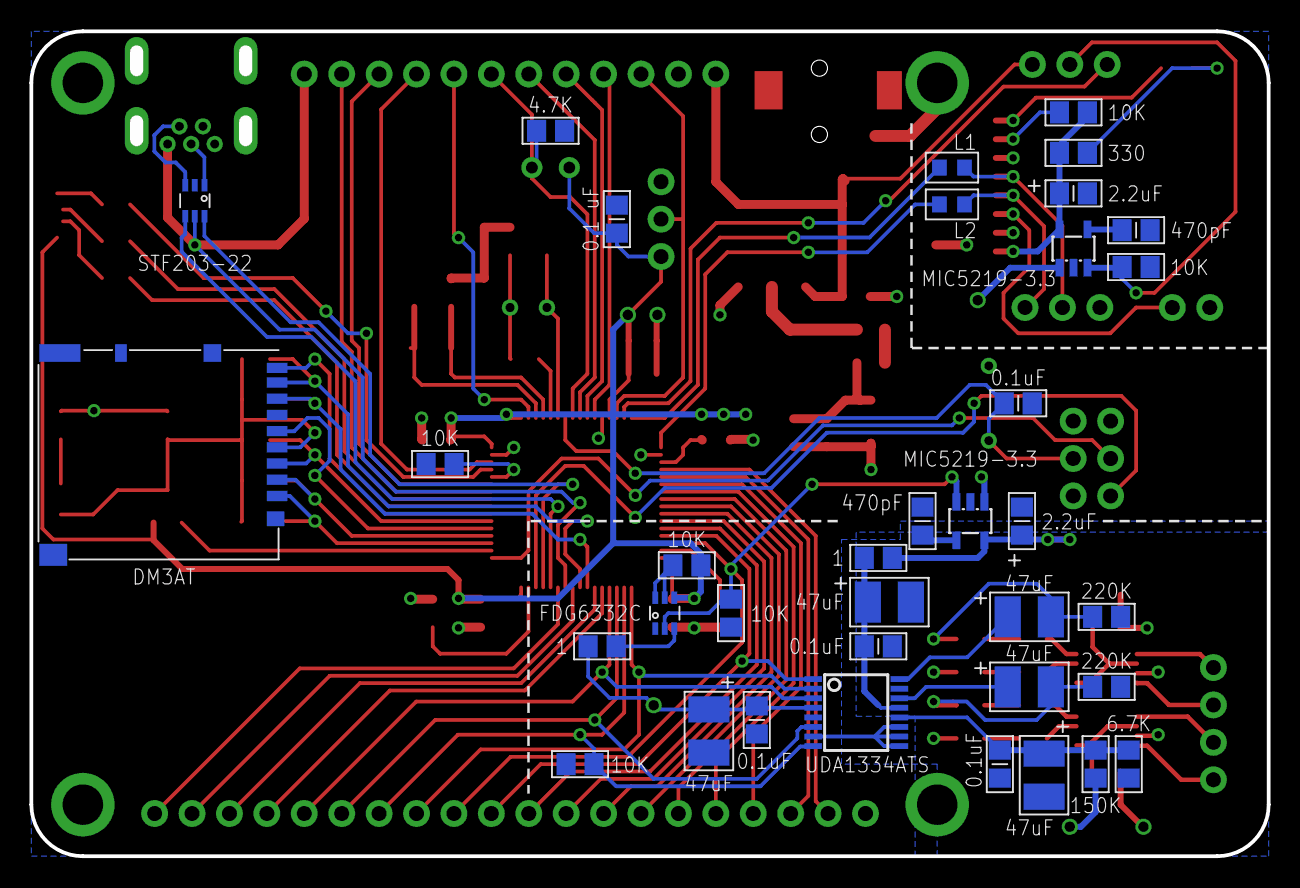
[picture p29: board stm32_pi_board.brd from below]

Board: 2 copper layers, 84.0 x 56.0 mm, 105 parts (36 on the bottom side), 99 nets.

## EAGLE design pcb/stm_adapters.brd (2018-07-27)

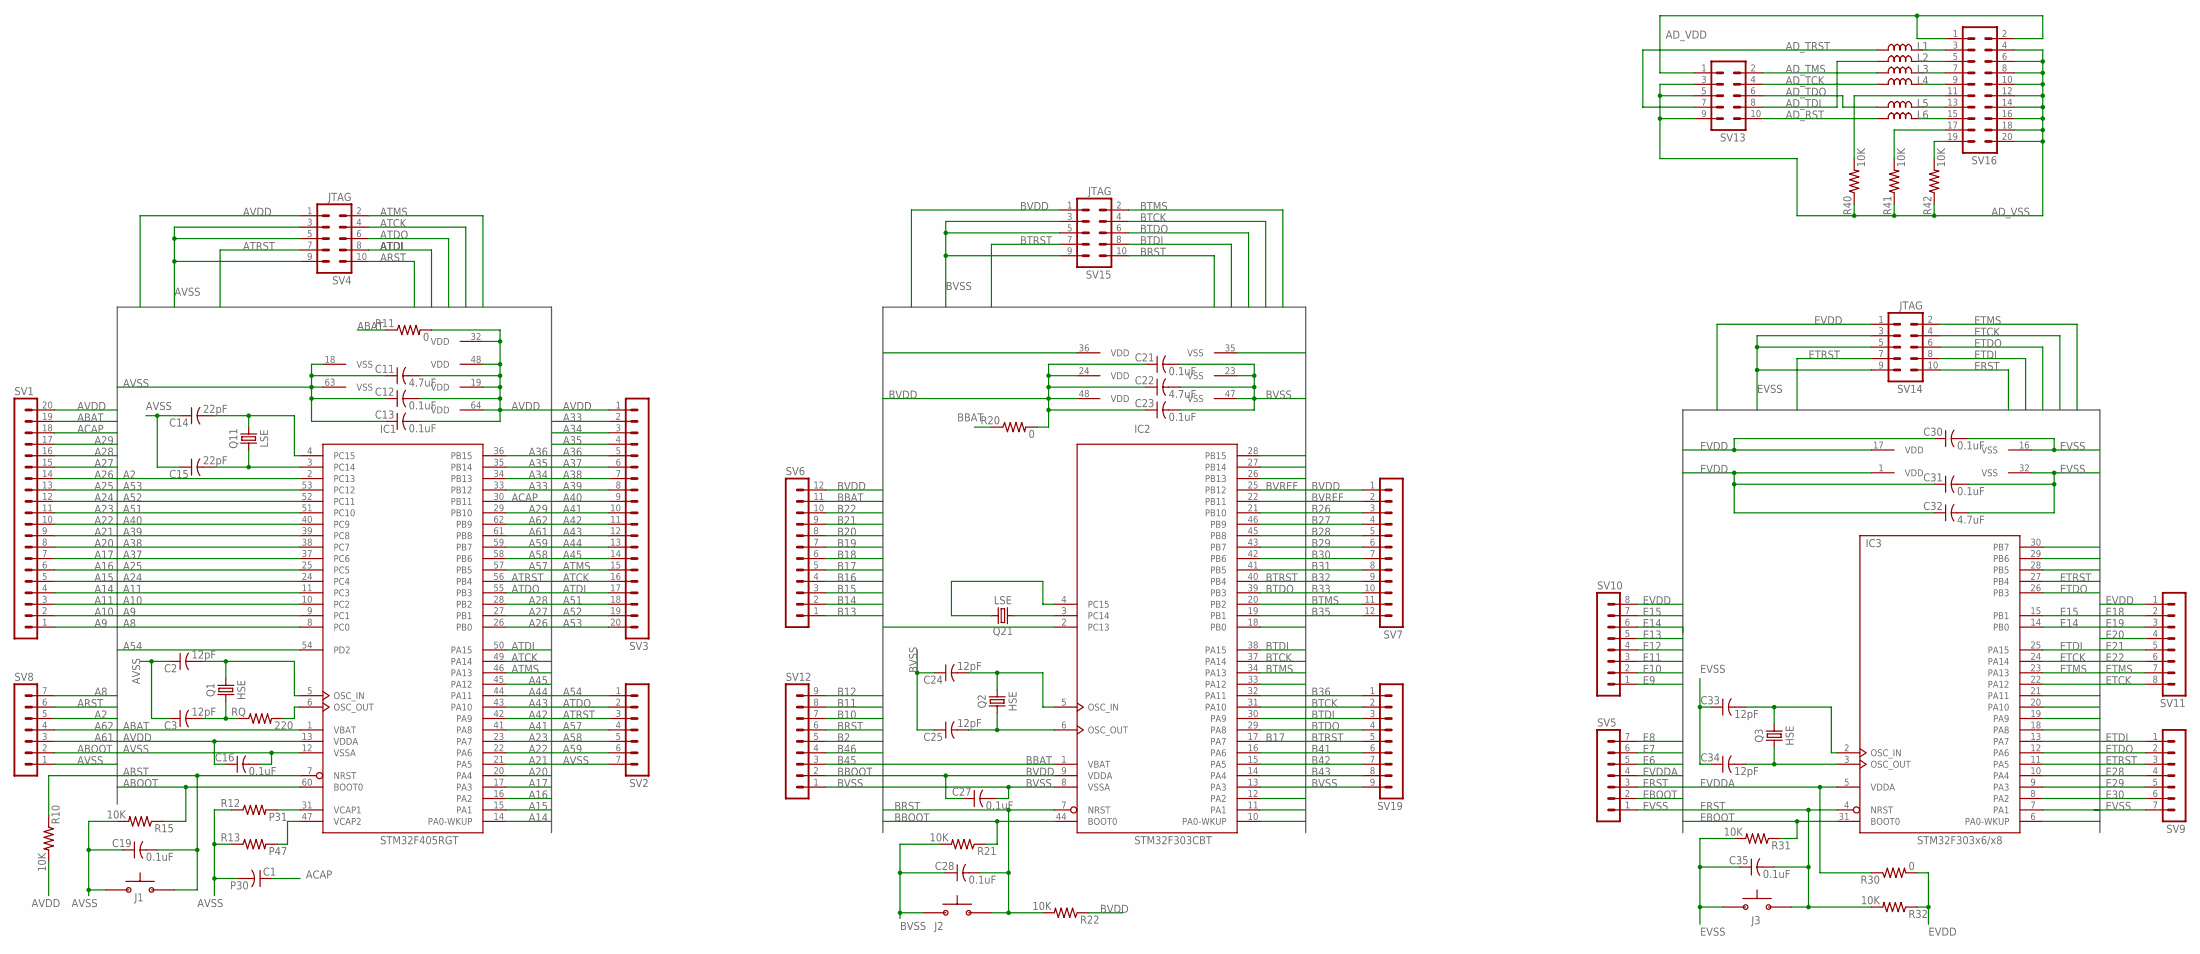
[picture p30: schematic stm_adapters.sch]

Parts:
C1: P30; C0805
C2, C3, C24, C25, C33, C34: 12pF; C0805
C11, C22, C32: 4.7uF; C0805
C12, C13, C16, C19, C21, C23, C27, C28, C30, C31, C35: 0.1uF; C0805
C14, C15: 22pF; C0805
IC1: STM32F405RGT; LQFP64
IC2: STM32F303CBT; LQFP48
IC3: STM32F303x6/x8; LQFP32
J1, J2, J3: BUTTON-FSM14JRT
L1, L2, L3, L4, L5, L6: L-USL0603; L0603
Q1, Q2, Q3: HSE; Q-HC-46X
Q11, Q21: LSE; Q-MC-306
R10, R15, R21, R22, R31, R32, R40, R41, R42: 10K; R0805
R11, R20, R30: 0; R0805
R12: P31; R0805
R13: P47; R0805
RQ: 220; R0805
SV1, SV3: MA20-1NO-PL; MA20-1-NO-PL
SV2, SV5, SV8, SV9: MA07-1NO-PL; MA07-1-NO-PL
SV4, SV14, SV15: JTAG; MA05-2
SV6, SV7: MA12-1NO-PL; MA12-1-NO-PL
SV10, SV11: MA08-1NO-PL; MA08-1-NO-PL
SV12, SV19: MA09-1NO-PL; MA09-1-NO-PL
SV13: MA05-2
SV16: MA10-2

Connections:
A2: IC1.2 (PC13), SV8.5
A8: IC1.8 (PC0), SV8.7
A9: IC1.9 (PC1), SV1.1
A10: IC1.10 (PC2), SV1.2
A11: IC1.11 (PC3), SV1.3
A14: IC1.14 (PA0-WKUP), SV1.4
A15: IC1.15 (PA1), SV1.5
A16: IC1.16 (PA2), SV1.6
A17: IC1.17 (PA3), SV1.7
A20: IC1.20 (PA4), SV1.8
A21: IC1.21 (PA5), SV1.9
A22: IC1.22 (PA6), SV1.10
A23: IC1.23 (PA7), SV1.11
A24: IC1.24 (PC4), SV1.12
A25: IC1.25 (PC5), SV1.13
A26: IC1.26 (PB0), SV1.14
A27: IC1.27 (PB1), SV1.15
A28: IC1.28 (PB2), SV1.16
A29: IC1.29 (PB10), SV1.17
A33: IC1.33 (PB12), SV3.2
A34: IC1.34 (PB13), SV3.3
A35: IC1.35 (PB14), SV3.4
A36: IC1.36 (PB15), SV3.5
A37: IC1.37 (PC6), SV3.6
A38: IC1.38 (PC7), SV3.7
A39: IC1.39 (PC8), SV3.8
A40: IC1.40 (PC9), SV3.9
A41: IC1.41 (PA8), SV3.10
A42: IC1.42 (PA9), SV3.11
A43: IC1.43 (PA10), SV3.12
A44: IC1.44 (PA11), SV3.13
A45: IC1.45 (PA12), SV3.14
A51: IC1.51 (PC10), SV3.18
A52: IC1.52 (PC11), SV3.19
A53: IC1.53 (PC12), SV3.20
A54: IC1.54 (PD2), SV2.1
A57: IC1.57 (PB5), SV2.4
A58: IC1.58 (PB6), SV2.5
A59: IC1.59 (PB7), SV2.6
A61: IC1.61 (PB8), SV8.3
A62: IC1.62 (PB9), SV8.4
ABAT: IC1.1 (VBAT), R11.1, SV1.19
ABOOT: IC1.60 (BOOT0), R15.1, SV8.2
ACAP: C1.1, IC1.30 (PB11), SV1.18
ACAP1: IC1.31 (VCAP1), R12.2
ACAP2: IC1.47 (VCAP2), R13.2
AD_RST: L6.1, SV13.10
AD_TCK: L4.1, SV13.4
AD_TDI: L2.1, SV13.8
AD_TDO: L5.1, SV13.6
AD_TMS: L3.1, SV13.2
AD_TRST: L1.1, SV13.7
AD_VDD: SV13.1, SV16.1, SV16.2
AD_VSS: R40.1, R41.1, R42.1, SV13.3, SV13.5, SV13.9, SV16.4, SV16.6, SV16.8, SV16.10, SV16.12, SV16.14, SV16.16, SV16.18, SV16.20
ARST: C19.2, IC1.7 (NRST), J1.P$2 (2), R10.1, SV4.10, SV8.6
ATCK: IC1.49 (PA14), SV3.16, SV4.4
ATDI: IC1.50 (PA15), SV3.17, SV4.8
ATDO: IC1.55 (PB3), SV2.2, SV4.6
ATMS: IC1.46 (PA13), SV3.15, SV4.2
ATRST: IC1.56 (PB4), SV2.3, SV4.7
AVDD: C11.2, C12.2, C13.2, C16.1, IC1.13 (VDDA), IC1.19 (VDD), IC1.32 (VDD), IC1.48 (VDD), IC1.64 (VDD), R10.2, R11.2, SV1.20, SV3.1, SV4.1
AVSS: C1.2, C2.1, C3.1, C11.1, C12.1, C13.1, C14.1, C15.1, C16.2, C19.1, IC1.12 (VSSA), IC1.18 (VSS), IC1.63 (VSS), J1.P$1 (1), R12.1, R13.1, R15.2, SV2.7, SV4.3, SV4.5, SV4.9, SV8.1
B2: IC2.2 (PC13), SV12.5
B10: IC2.10 (PA0-WKUP), SV12.7
B11: IC2.11 (PA1), SV12.8
B12: IC2.12 (PA2), SV12.9
B13: IC2.13 (PA3), SV6.1
B14: IC2.14 (PA4), SV6.2
B15: IC2.15 (PA5), SV6.3
B16: IC2.16 (PA6), SV6.4
B17: IC2.17 (PA7), SV6.5
B18: IC2.18 (PB0), SV6.6
B19: IC2.19 (PB1), SV6.7
B20: IC2.20 (PB2), SV6.8
B21: IC2.21 (PB10), SV6.9
B22: IC2.22 (PB11), SV6.10
B26: IC2.26 (PB13), SV7.3
B27: IC2.27 (PB14), SV7.4
B28: IC2.28 (PB15), SV7.5
B29: IC2.29 (PA8), SV7.6
B30: IC2.30 (PA9), SV7.7
B31: IC2.31 (PA10), SV7.8
B32: IC2.32 (PA11), SV7.9
B33: IC2.33 (PA12), SV7.10
B35: IC2.35 (VSS), SV7.12
B36: IC2.36 (VDD), SV19.1
B41: IC2.41 (PB5), SV19.6
B42: IC2.42 (PB6), SV19.7
B43: IC2.43 (PB7), SV19.8
B45: IC2.45 (PB8), SV12.3
B46: IC2.46 (PB9), SV12.4
BBAT: IC2.1 (VBAT), R20.1, SV6.11
BBOOT: IC2.44 (BOOT0), R21.1, SV12.2
BRST: C28.2, IC2.7 (NRST), J2.P$2 (2), R22.2, SV12.6, SV15.10
BTCK: IC2.37 (PA14), SV15.4, SV19.2
BTDI: IC2.38 (PA15), SV15.8, SV19.3
BTDO: IC2.39 (PB3), SV15.6, SV19.4
BTMS: IC2.34 (PA13), SV7.11, SV15.2
BTRST: IC2.40 (PB4), SV15.7, SV19.5
BVDD: C21.1, C22.1, C23.1, C27.1, IC2.9 (VDDA), IC2.24 (VDD), IC2.48 (VDD), R20.2, R22.1, SV6.12, SV7.1, SV15.1
BVREF: IC2.25 (PB12), SV7.2
BVSS: C21.2, C22.2, C23.2, C24.1, C25.1, C27.2, C28.1, IC2.8 (VSSA), IC2.23 (VSS), IC2.47 (VSS), J2.P$1 (1), R21.2, SV12.1, SV15.3, SV15.5, SV15.9, SV19.9
E6: IC3.6 (PA0-WKUP), SV5.5
E7: IC3.7 (PA1), SV5.6
E8: IC3.8 (PA2), SV5.7
E9: IC3.9 (PA3), SV10.1
E10: IC3.10 (PA4), SV10.2
E11: IC3.11 (PA5), SV10.3
E12: IC3.12 (PA6), SV10.4
E13: IC3.13 (PA7), SV10.5
E14: IC3.14 (PB0), SV10.6
E15: IC3.15 (PB1), SV10.7
E18: IC3.18 (PA8), SV11.2
E19: IC3.19 (PA9), SV11.3
E20: IC3.20 (PA10), SV11.4
E21: IC3.21 (PA11), SV11.5
E22: IC3.22 (PA12), SV11.6
E28: IC3.28 (PB5), SV9.4
E29: IC3.29 (PB6), SV9.5
E30: IC3.30 (PB7), SV9.6
EBOOT: IC3.31 (BOOT0), R31.1, SV5.2
ERST: C35.2, IC3.4 (NRST), J3.P$2 (2), R32.2, SV5.3, SV14.10
ETCK: IC3.24 (PA14), SV11.8, SV14.4
ETDI: IC3.25 (PA15), SV9.1, SV14.8
ETDO: IC3.26 (PB3), SV9.2, SV14.6
ETMS: IC3.23 (PA13), SV11.7, SV14.2
ETRST: IC3.27 (PB4), SV9.3, SV14.7
EVDD: C30.1, C31.1, C32.1, IC3.1 (VDD), IC3.17 (VDD), R30.2, R32.1, SV10.8, SV11.1, SV14.1
EVDDA: IC3.5 (VDDA), R30.1, SV5.4
EVSS: C30.2, C31.2, C32.2, C33.1, C34.1, C35.1, IC3.16 (VSS), IC3.32 (VSS), J3.P$1 (1), R31.2, SV5.1, SV9.7, SV14.3, SV14.5, SV14.9
unnamed: R42.2, SV16.19
unnamed: R41.2, SV16.17
unnamed: R40.2, SV16.11
unnamed: L6.2, SV16.15
unnamed: L5.2, SV16.13
unnamed: L4.2, SV16.9
unnamed: C24.2, IC2.5 (OSC_IN), Q2.1
unnamed: C25.2, IC2.6 (OSC_OUT), Q2.2
unnamed: L3.2, SV16.7
unnamed: IC2.3 (PC14), Q21.1
unnamed: IC2.4 (PC15), Q21.4 (2)
unnamed: L2.2, SV16.5
unnamed: L1.2, SV16.3
unnamed: C34.2, IC3.3 (OSC_OUT), Q3.1
unnamed: C33.2, IC3.2 (OSC_IN), Q3.2
unnamed: C15.2, IC1.3 (PC14), Q11.1
unnamed: C14.2, IC1.4 (PC15), Q11.4 (2)
unnamed: C2.2, IC1.5 (OSC_IN), Q1.1
unnamed: IC1.6 (OSC_OUT), RQ.2
unnamed: C3.2, Q1.2, RQ.1

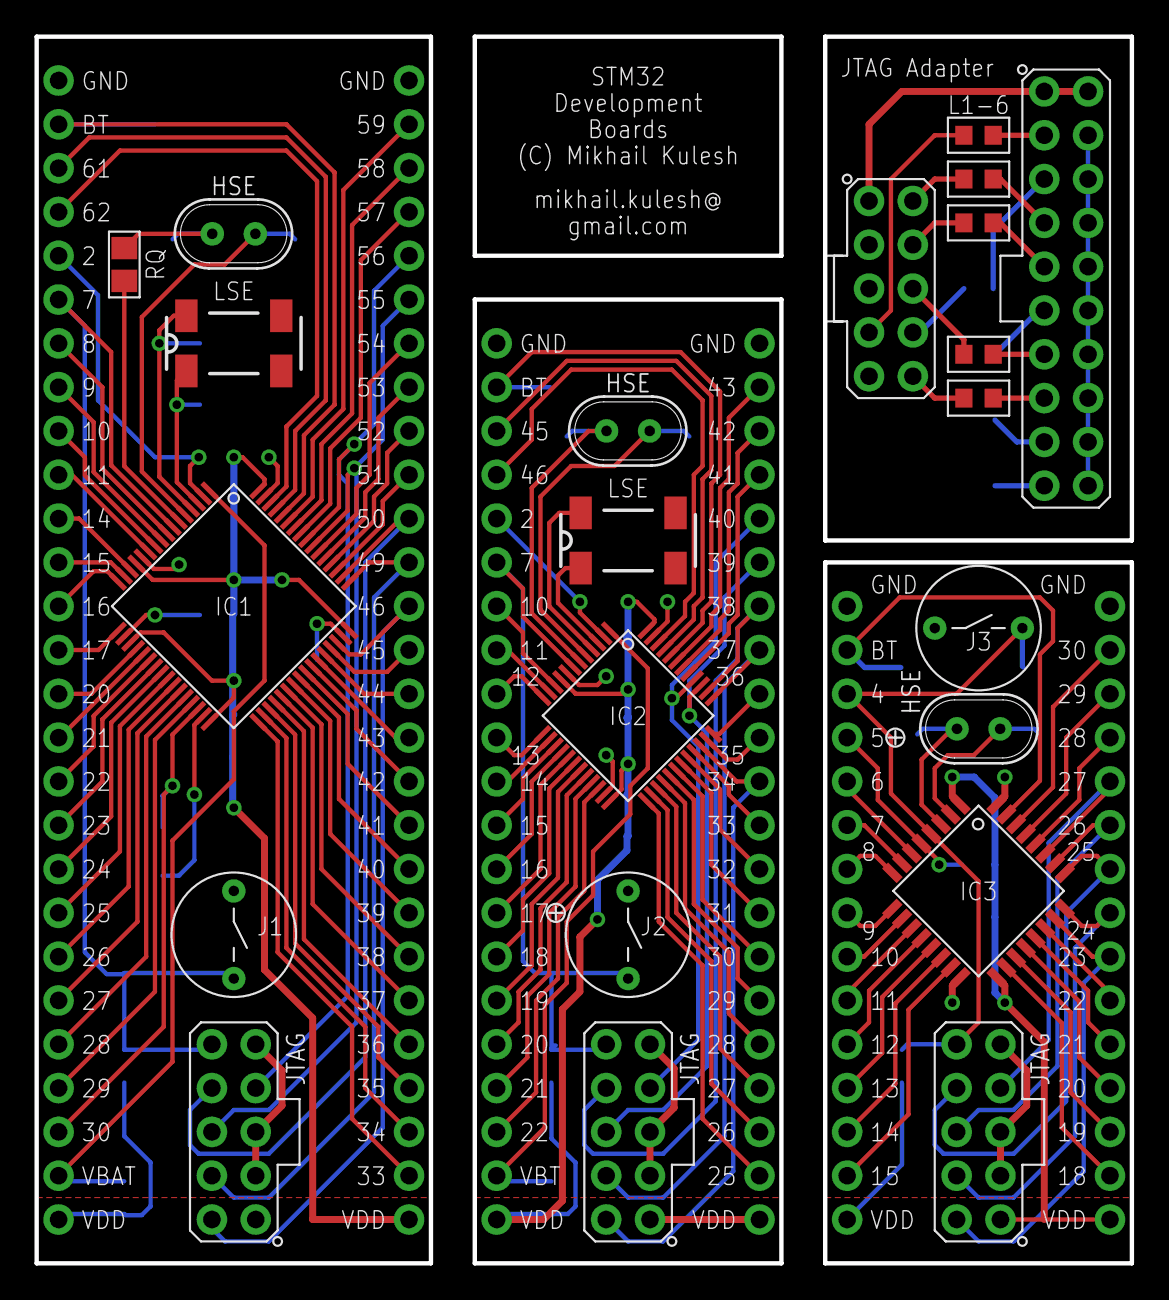
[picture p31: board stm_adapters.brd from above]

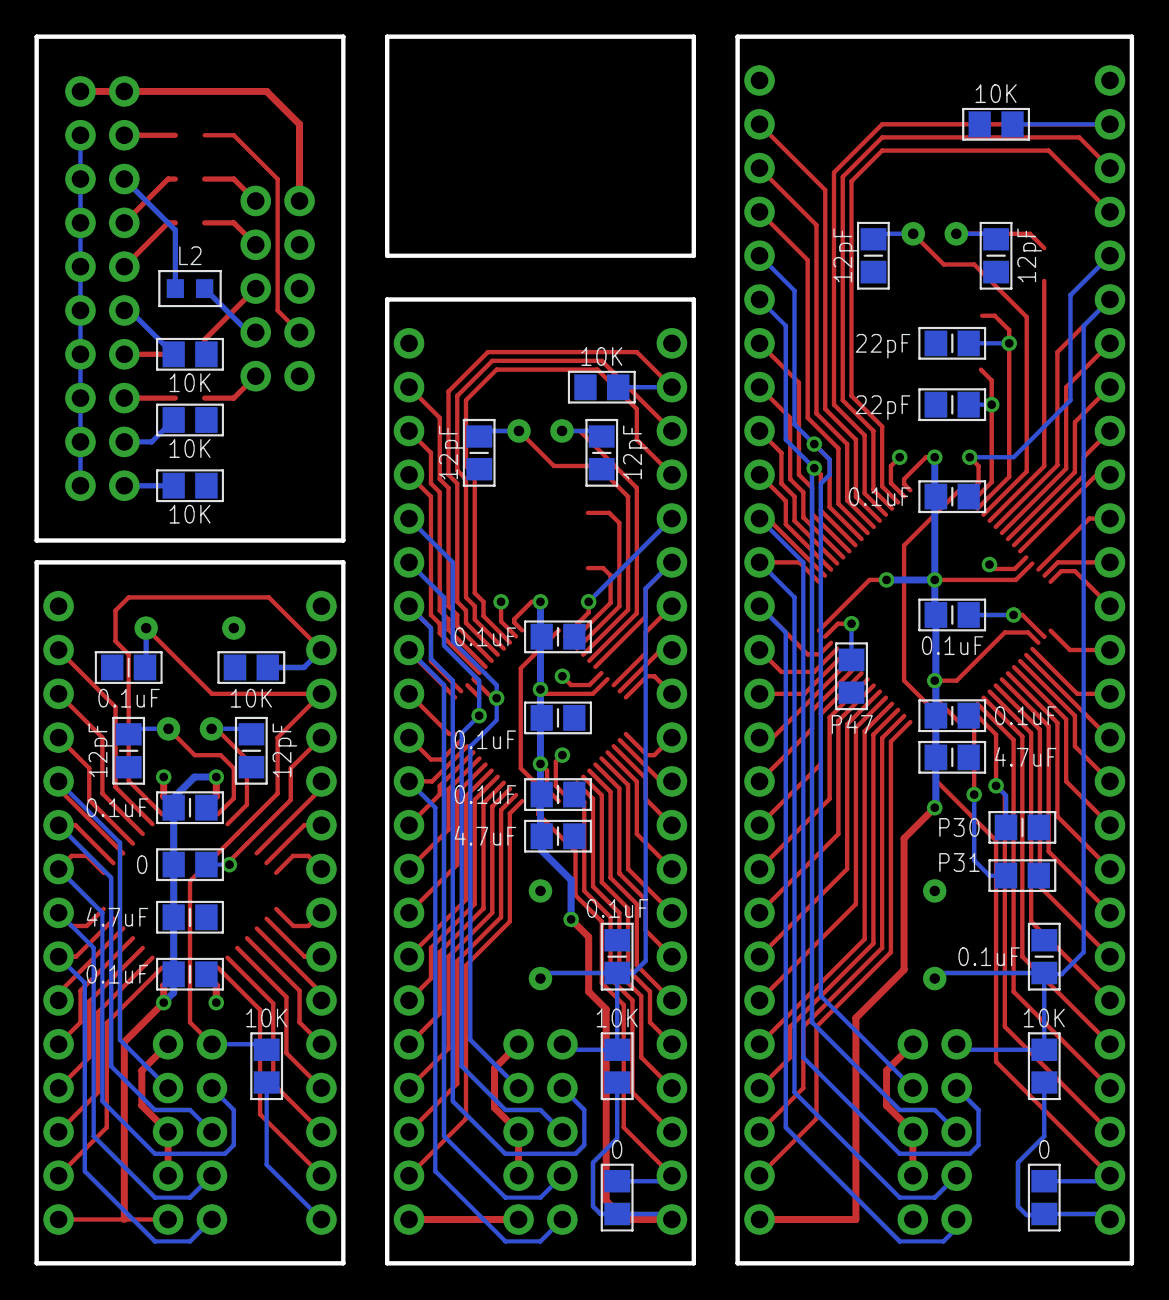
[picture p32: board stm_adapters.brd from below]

Board: 2 copper layers, 63.5 x 71.1 mm, 72 parts (50 on the bottom side), 150 nets.

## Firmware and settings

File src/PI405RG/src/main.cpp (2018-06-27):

/*******************************************************************************
 * Test unit for the development board: STM32F405RGT6
 * *****************************************************************************
 * Copyright (C) 2016-2017 Mikhail Kulesh
 *
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
 * You should have received a copy of the GNU General Public License
 * along with this program.  If not, see <http://www.gnu.org/licenses/>.
 ******************************************************************************/

#include "HardwareMap.h"
#include "StmPlusPlus/StmPlusPlus.h"
#include "StmPlusPlus/WavStreamer.h"
#include "StmPlusPlus/Devices/Button.h"
#include "StmPlusPlus/Devices/Ssd.h"
#include "EspSender.h"
#include "EventQueue.h"

#include <array>
#include <cmath>

using namespace StmPlusPlus;
using namespace StmPlusPlus::Devices;

#define USART_DEBUG_MODULE "Main: "

// Globally defined hardware device list
MyHardware::PortA portA;
MyHardware::PortB portB;
MyHardware::PortC portC;
MyHardware::PortD portD;
MyHardware::Rtc devRtc (RTC_WKUP_IRQn, 2, 0);

MyHardware::Sdio devSdio (
    &portC, /*SDIO_D0*/GPIO_PIN_8 | /*SDIO_D1*/GPIO_PIN_9 | /*SDIO_D2*/GPIO_PIN_10 | /*SDIO_D3*/GPIO_PIN_11 | /*SDIO_CK*/GPIO_PIN_12,
    &portD, /*SDIO_CMD*/GPIO_PIN_2,
    HardwareLayout::Interrupt(SDIO_IRQn, 3, 0),
    HardwareLayout::Interrupt(DMA2_Stream6_IRQn, 4, 0),
    HardwareLayout::DmaStream(DMA2_Stream6, DMA_CHANNEL_4),
    HardwareLayout::Interrupt(DMA2_Stream3_IRQn, 5, 0),
    HardwareLayout::DmaStream(DMA2_Stream3, DMA_CHANNEL_4));

MyHardware::I2S devI2S (
    &portB, /*I2S2_CK*/GPIO_PIN_10 | /*I2S2_WS*/GPIO_PIN_12 | /*I2S2_SD*/GPIO_PIN_15,
    HardwareLayout::Interrupt(DMA1_Stream4_IRQn, 6, 0),
    HardwareLayout::DmaStream(DMA1_Stream4, DMA_CHANNEL_0));

MyHardware::Usart1 devUsart1 (
    &portB, GPIO_PIN_6,
    &portB, GPIO_PIN_7,
    HardwareLayout::Interrupt(USART1_IRQn, 15, 0));

MyHardware::Usart2 devUsart2 (
    &portA, GPIO_PIN_2,
    &portA, GPIO_PIN_3,
    HardwareLayout::Interrupt(USART2_IRQn, 8, 0));

MyHardware::Spi1 devSpi1(&portA, GPIO_PIN_5 | GPIO_PIN_7,
    HardwareLayout::Interrupt(DMA2_Stream5_IRQn, 9, 0),
    HardwareLayout::DmaStream(DMA2_Stream5, DMA_CHANNEL_3));

MyHardware::Timer3 devTimer3(HardwareLayout::Interrupt(TIM3_IRQn, 10, 0));
MyHardware::Timer5 devTimer5(HardwareLayout::Interrupt(TIM5_IRQn, 11, 0));

MyHardware::Adc1 adc1(&portA, GPIO_PIN_0,
    HardwareLayout::Interrupt(DMA2_Stream0_IRQn, 12, 0),
    HardwareLayout::DmaStream(DMA2_Stream0, DMA_CHANNEL_0));


class MyApplication : public WavStreamer::EventHandler, Devices::Button::EventHandler
{
public:

    static const size_t INPUT_PINS = 4;  // Number of monitored input pins
    static const uint32_t HEARTBEAT_LONG_DELAY = 999;
    static const uint32_t HEARTBEAT_SHORT_DELAY = 30;
    static const uint32_t NTP_REQUEST_DELAY = 30*1000;

    enum class EventType
    {
        SECOND_INTERRUPT = 0,
        HEARTBEAT_INTERRUPT = 1,
        NTP_REQUEST = 2,
        ADC1_READY = 3
    };

private:
    
    UsartLogger log;

    EventQueue<EventType, 100> eventQueue;

    RealTimeClock rtc;
    IOPin mco;

    IOPin ledGreen, ledBlue, ledRed;
    Timer heartbeatTimer;

    // SD card
    IOPin pinSdPower, pinSdDetect;
    SdCard sdCard;
    bool sdCardInserted;

    // Configuration
    Config config;

    // ESP
    Esp11 esp;
    EspSender espSender;

    // Input pins
    std::array<IOPin, INPUT_PINS> pins;
    std::array<bool, INPUT_PINS> pinsState;

    // Message
    char messageBuffer[2048];

    // I2S2 Audio
    I2S i2s;
    AudioDac_UDA1334 audioDac;
    WavStreamer streamer;
    Devices::Button playButton;

    // NTP data
    struct RealTimeClock::NtpPacket ntpPacket;
    Timer ntpRequestTimer;
    bool ntpRequestActive;

    // ADC
    AnalogToDigitConverter adc;

    // SSD
    Spi spi;
    IOPin pinSsdCs;
    Devices::Ssd_74HC595_SPI ssd;
    char localTime[24];

public:
    
    MyApplication () :
            // logging
            log(&devUsart1, 115200),

            // RTC
            rtc(&devRtc),
            mco(IOPort::A, GPIO_PIN_8, GPIO_MODE_AF_PP),

            ledGreen(IOPort::C, GPIO_PIN_1, GPIO_MODE_OUTPUT_PP),
            ledBlue(IOPort::C, GPIO_PIN_2, GPIO_MODE_OUTPUT_PP),
            ledRed(IOPort::C, GPIO_PIN_3, GPIO_MODE_OUTPUT_PP),

            heartbeatTimer(&devTimer5),

            // SD card
            pinSdPower(IOPort::A, GPIO_PIN_15, GPIO_MODE_OUTPUT_PP, GPIO_PULLDOWN, GPIO_SPEED_HIGH, true, false),
            pinSdDetect(IOPort::B, GPIO_PIN_3, GPIO_MODE_INPUT, GPIO_PULLUP),
            sdCard(&devSdio, pinSdDetect),
            sdCardInserted(false),
            
            // Configuration
            config(pinSdPower, sdCard, "conf.txt"),

            //ESP
            esp(&devUsart2, IOPort::A, GPIO_PIN_1),
            espSender(esp, ledRed),

            // Input pins
            pins { { IOPin(IOPort::C, GPIO_PIN_4,  GPIO_MODE_INPUT, GPIO_PULLUP),
                     IOPin(IOPort::C, GPIO_PIN_5,  GPIO_MODE_INPUT, GPIO_PULLUP),
                     IOPin(IOPort::B, GPIO_PIN_0,  GPIO_MODE_INPUT, GPIO_PULLUP),
                     IOPin(IOPort::B, GPIO_PIN_1,  GPIO_MODE_INPUT, GPIO_PULLUP)
            } },

            // Audio
            i2s(&devI2S),
            audioDac(i2s,
                     /* power    = */ IOPort::B, GPIO_PIN_11,
                     /* mute     = */ IOPort::B, GPIO_PIN_13,
                     /* smplFreq = */ IOPort::B, GPIO_PIN_14),
            streamer(sdCard, audioDac),
            playButton(IOPort::B, GPIO_PIN_2, GPIO_PULLUP),

            // NTP
            ntpRequestTimer(&devTimer3),
            ntpRequestActive(false),

            // ADC
            adc(&adc1, 0, ADC_SAMPLETIME_56CYCLES, 3.06),

            // SSD
            spi(&devSpi1, GPIO_PULLUP),
            pinSsdCs(IOPort::A, GPIO_PIN_6, GPIO_MODE_OUTPUT_PP, GPIO_PULLUP, GPIO_SPEED_HIGH, true, true),
            ssd(spi, pinSsdCs, true)
    {
        mco.activateClockOutput(RCC_MCO1SOURCE_PLLCLK, RCC_MCODIV_5);
        Devices::Ssd::SegmentsMask sm;
        sm.top = 3;
        sm.rightTop = 5;
        sm.rightBottom = 7;
        sm.bottom = 4;
        sm.leftBottom = 1;
        sm.leftTop = 2;
        sm.center = 6;
        sm.dot = 0;
        ssd.setSegmentsMask(sm);
    }
    
    virtual ~MyApplication ()
    {
        // empty
    }
    
    inline void scheduleEvent (EventType t)
    {
        eventQueue.put(t);
    }

    inline I2S & getI2S ()
    {
        return i2s;
    }

    inline Esp11 & getEsp ()
    {
        return esp;
    }

    inline const Timer & getHeartBeatTimer () const
    {
        return heartbeatTimer;
    }

    inline const Timer & getNtpRequestTimer () const
    {
        return ntpRequestTimer;
    }

    inline Spi & getSpi ()
    {
        return spi;
    }

    inline AnalogToDigitConverter & getAdc ()
    {
        return adc;
    }

    void run ()
    {
        log.initInstance();
        rtc.initInstance();

        USART_DEBUG("--------------------------------------------------------");
        USART_DEBUG("Oscillator frequency: " << System::getInstance()->getHSEFreq()
                    << ", MCU frequency: " << System::getInstance()->getMcuFreq());
        
        HAL_StatusTypeDef status = HAL_TIMEOUT;
        rtc.stop();
        do
        {
            status = rtc.start(8 * 2047 + 7, RTC_WAKEUPCLOCK_RTCCLK_DIV2, NULL);
            USART_DEBUG("RTC start status: " << status);
        }
        while (status != HAL_OK);

        sdCard.initInstance();
        if (sdCard.isCardInserted())
        {
            updateSdCardState();
        }
        
        USART_DEBUG("Input pins: " << pins.size());
        pinsState.fill(true);
        USART_DEBUG("Pin state: " << fillMessage());
        esp.assignSendLed(&ledBlue);

        streamer.stop();
        streamer.setHandler(this);
        streamer.setVolume(0.5);
        playButton.setHandler(this);

        // start ADC
        adc.stop();
        adc.start();

        // SPI and SSD
        spi.start(SPI_DIRECTION_1LINE, SPI_BAUDRATEPRESCALER_64, SPI_DATASIZE_8BIT, SPI_PHASE_2EDGE);
        ssd.putString("0000", NULL, 4);

        // start timers
        uint32_t timerPrescaler = SystemCoreClock/4000 - 1;
        USART_DEBUG("Timer prescaler: " << timerPrescaler);
        heartbeatTimer.start(TIM_COUNTERMODE_UP, timerPrescaler, HEARTBEAT_LONG_DELAY);
        ntpRequestTimer.start(TIM_COUNTERMODE_UP, timerPrescaler, NTP_REQUEST_DELAY);

        bool reportState = false;
        while (true)
        {
            if (!eventQueue.empty())
            {
                switch (eventQueue.get())
                {
                case EventType::SECOND_INTERRUPT:
                    handleSeconds();
                    handleNtpRequest();
                    break;

                case EventType::HEARTBEAT_INTERRUPT:
                    handleHeartbeat();
                    break;

                case EventType::NTP_REQUEST:
                    ntpRequestActive = true;
                    handleNtpRequest();
                    break;
                case EventType::ADC1_READY:
                    USART_DEBUG("ADC1: " << adc.getMV() << ", " << (int)(lmt86Temperature(adc.getMV())*10.0));
                    break;
                }
            }
            updateSdCardState();
            playButton.periodic();
            streamer.periodic();

            if (isInputPinsChanged())
            {
                USART_DEBUG("Input pins change detected");
                ledBlue.putBit(true);
                reportState = true;
            }

            espSender.periodic();
            if (espSender.isOutputMessageSent())
            {
                if (reportState)
                {
                    espSender.sendMessage(config, "TCP", config.getServerIp(), config.getServerPort(), fillMessage());
                    reportState = false;
                }
                if (!reportState)
                {
                    ledBlue.putBit(false);
                }
            }

            if (esp.getInputMessageSize() > 0)
            {
                esp.getInputMessage(messageBuffer, esp.getInputMessageSize());
                ::memcpy(&ntpPacket, messageBuffer, RealTimeClock::NTP_PACKET_SIZE);
                rtc.decodeNtpMessage(ntpPacket);
                ntpRequestActive = false;
                ntpRequestTimer.reset();
            }
        }
    }
    
    void handleSeconds ()
    {
        time_t total_secs = rtc.getTimeSec();
        struct tm * now = ::gmtime(&total_secs);
        sprintf(localTime, "%02d%02d", now->tm_min, now->tm_sec);
        spi.waitForRelease();
        ssd.putString(localTime, NULL, 4);
        if (rtc.getTimeSec() > 1000)
        {
            if (!streamer.isActive())
            {
                //onButtonPressed(&playButton, 1);
            }
            adc.readDma();
        }
    }

    void handleHeartbeat ()
    {
        ledGreen.putBit(!ledGreen.getBit());
        heartbeatTimer.reset();
        heartbeatTimer.setPeriod(ledGreen.getBit()? HEARTBEAT_SHORT_DELAY : HEARTBEAT_LONG_DELAY);
    }

    void handleNtpRequest ()
    {
        if (ntpRequestActive && espSender.isOutputMessageSent())
        {
            rtc.fillNtpRrequst(ntpPacket);
            espSender.sendMessage(config, "UDP", config.getNtpServer(), "123", (const char *)(&ntpPacket), RealTimeClock::NTP_PACKET_SIZE);
        }
    }

    bool isInputPinsChanged ()
    {
        bool isChanged = false;
        for (size_t i = 0; i < INPUT_PINS; ++i)
        {
            if (pins[i].getBit() != pinsState[i])
            {
                isChanged = true;
                pinsState[i] = pins[i].getBit();
            }
        }
        return isChanged;
    }
    
    void updateSdCardState ()
    {
        if (!sdCardInserted && sdCard.isCardInserted())
        {
            config.readConfiguration();
        }
        sdCardInserted = sdCard.isCardInserted();
    }

    const char * fillMessage ()
    {
        char digits[9];
        ::__utoa(rtc.getTimeSec(), digits, 10);
        ::strcpy(messageBuffer, "<message>");
        ::strcat(messageBuffer, "<name>BOARD_STATE</name>");
        // the first parameter: board ID
        ::strcat(messageBuffer, "<p>");
        ::strcat(messageBuffer, config.getBoardId());
        ::strcat(messageBuffer, "</p>");
        // the second parameter: state
        ::strcat(messageBuffer, "<p>");
        for (auto &p : pins)
        {
            ::__itoa(p.getBit(), digits, 10);
            ::strcat(messageBuffer, digits);
        }
        ::strcat(messageBuffer, "</p>");
        ::strcat(messageBuffer, "</message>");
        return &messageBuffer[0];
    }

    virtual bool onStartSteaming (Devices::AudioDac_UDA1334::SourceType s)
    {
        if (s == Devices::AudioDac_UDA1334::SourceType::STREAM)
        {
            if (!sdCard.isCardInserted())
            {
                USART_DEBUG("SD Card is not inserted");
                return false;
            }
            pinSdPower.setLow();
            HAL_Delay(250);
        }
        return true;
    }

    virtual void onFinishSteaming ()
    {
        pinSdPower.setHigh();
    }

    virtual void onButtonPressed (const Devices::Button * b, uint32_t numOccured)
    {
        if (b == &playButton)
        {
            USART_DEBUG("play button pressed: " << numOccured);
            if (streamer.isActive())
            {
                USART_DEBUG("    Stopping WAV");
                streamer.stop();
            }
            else if (sdCard.isCardInserted())
            {
                USART_DEBUG("    Starting WAV");
                streamer.start(AudioDac_UDA1334::SourceType:: STREAM, config.getWavFile());
            }
        }
    }

    float lmt86Temperature (int mv)
    {
        return 30.0 + (10.888 - ::sqrt(10.888*10.888 + 4.0*0.00347*(1777.3 - (float)mv)))/(-2.0*0.00347);
    }
};

MyApplication * appPtr = NULL;

int main (void)
{
    // Note: check the Value of the External oscillator mounted in PCB
    // and set this value in the file stm32f4xx_hal_conf.h
    
    HAL_Init();
    
    IOPort defaultPortA(IOPort::PortName::A, GPIO_MODE_INPUT, GPIO_PULLDOWN);
    IOPort defaultPortB(IOPort::PortName::B, GPIO_MODE_INPUT, GPIO_PULLDOWN);
    IOPort defaultPortC(IOPort::PortName::C, GPIO_MODE_INPUT, GPIO_PULLDOWN);
    
    // Set system frequency to 168MHz
    System sys{HardwareLayout::Interrupt{SysTick_IRQn, 0, 0}};
    sys.initHSE(/*external=*/ true);
    sys.initPLL(16, 336, 2, 7);
    sys.initLSE(/*external=*/ true);
    sys.initAHB(RCC_SYSCLK_DIV1, RCC_HCLK_DIV8, RCC_HCLK_DIV8);
    sys.initRTC();
    sys.initI2S(192, 2);
    do
    {
        sys.start(FLASH_LATENCY_3);
    }
    while (sys.getMcuFreq() != 168000000L);
    sys.initInstance();
    
    __HAL_RCC_DMA1_CLK_ENABLE();
    __HAL_RCC_DMA2_CLK_ENABLE();

    MyApplication app;
    appPtr = &app;
    
    app.run();
}

extern "C"
{
// System and RTC
void SysTick_Handler (void)
{
    HAL_IncTick();
    if (RealTimeClock::getInstance() != NULL)
    {
        RealTimeClock::getInstance()->onMilliSecondInterrupt();
    }
}

void RTC_WKUP_IRQHandler ()
{
    if (RealTimeClock::getInstance() != NULL)
    {
        RealTimeClock::getInstance()->onSecondInterrupt();
    }
    appPtr->scheduleEvent(MyApplication::EventType::SECOND_INTERRUPT);
}

// Timers
void TIM3_IRQHandler ()
{
    appPtr->getNtpRequestTimer().processInterrupt();
    appPtr->scheduleEvent(MyApplication::EventType::NTP_REQUEST);
}

void TIM5_IRQHandler ()
{
    appPtr->getHeartBeatTimer().processInterrupt();
    appPtr->scheduleEvent(MyApplication::EventType::HEARTBEAT_INTERRUPT);
}

// SD card
void DMA2_Stream3_IRQHandler (void)
{
    Devices::SdCard::getInstance()->processDmaRxInterrupt();
}

void DMA2_Stream6_IRQHandler (void)
{
    Devices::SdCard::getInstance()->processDmaTxInterrupt();
}

void SDIO_IRQHandler (void)
{
    Devices::SdCard::getInstance()->processSdIOInterrupt();
}

// UART
void USART1_IRQHandler(void)
{
    if (IS_USART_DEBUG_ACTIVE())
    {
        UsartLogger::getInstance()->processInterrupt();
    }
}

void USART2_IRQHandler (void)
{
    appPtr->getEsp().processInterrupt();
}

void HAL_UART_TxCpltCallback (UART_HandleTypeDef * channel)
{
    if (channel->Instance == USART1 && IS_USART_DEBUG_ACTIVE())
    {
        UsartLogger::getInstance()->processRxTxCpltCallback();
    }
    else if (channel->Instance == USART2)
    {
        appPtr->getEsp().processTxCpltCallback();
    }
}

void HAL_UART_RxCpltCallback (UART_HandleTypeDef * channel)
{
    if (channel->Instance == USART1 && IS_USART_DEBUG_ACTIVE())
    {
        UsartLogger::getInstance()->processRxTxCpltCallback();
    }
    else if (channel->Instance == USART2)
    {
        appPtr->getEsp().processRxCpltCallback();
    }
}

void HAL_UART_ErrorCallback (UART_HandleTypeDef * channel)
{
    if (channel->Instance == USART1 && IS_USART_DEBUG_ACTIVE())
    {
        UsartLogger::getInstance()->processRxTxCpltCallback();
    }
    else if (channel->Instance == USART2)
    {
        appPtr->getEsp().processErrorCallback();
    }
}

// SPI
void DMA2_Stream5_IRQHandler (void)
{
    appPtr->getSpi().processDmaTxInterrupt();
}

void HAL_SPI_TxCpltCallback(SPI_HandleTypeDef *hspi)
{
    if (hspi->Instance == SPI1)
    {
        appPtr->getSpi().processTxCpltCallback();
    }
}

// I2S
void DMA1_Stream4_IRQHandler(void)
{
    appPtr->getI2S().processDmaTxInterrupt();
}

void HAL_I2S_TxCpltCallback(I2S_HandleTypeDef *channel)
{
    appPtr->getI2S().processTxCpltCallback();
}

// ADC
void DMA2_Stream0_IRQHandler()
{
    appPtr->getAdc().processDmaRxInterrupt();
}

void HAL_ADC_ConvCpltCallback(ADC_HandleTypeDef* channel)
{
    if (appPtr->getAdc().processConvCpltCallback())
    {
        appPtr->scheduleEvent(MyApplication::EventType::ADC1_READY);
    }
}

}

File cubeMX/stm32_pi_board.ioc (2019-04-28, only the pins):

Mcu.UserName=STM32F405RGTx
PA1.GPIO_Label=ESP-ON
PA1.Signal=GPIO_Output
PA11.Signal=USB_OTG_FS_DM
PA12.Signal=USB_OTG_FS_DP
PA13.Signal=SYS_JTMS-SWDIO
PA14.Signal=SYS_JTCK-SWCLK
PA15.GPIO_Label=SD-ON
PA15.Signal=GPIO_Output
PA2.GPIO_Label=ESP-TX
PA2.Signal=USART2_TX
PA3.GPIO_Label=ESP-RX
PA3.Signal=USART2_RX
PA4.Signal=GPXTI4
PA5.Signal=SPI1_SCK
PA6.Signal=SPI1_MISO
PA7.Signal=SPI1_MOSI
PA8.Signal=RCC_MCO_1
PA9.Signal=USB_OTG_FS_VBUS
PB10.GPIO_Label=AUD-BCK
PB10.Signal=I2S2_CK
PB11.GPIO_Label=AUD-ON
PB11.Signal=GPIO_Output
PB12.GPIO_Label=AUD-WS
PB12.Signal=I2S2_WS
PB13.GPIO_Label=AUD-MUTE
PB13.Signal=GPIO_Output
PB14.GPIO_Label=AUD-SMPL
PB14.Signal=GPIO_Output
PB15.GPIO_Label=AUD-DAT
PB15.Signal=I2S2_SD
PB3.GPIO_Label=SD-DET
PB3.Signal=GPIO_Input
PB6.Signal=USART1_TX
PB7.Signal=USART1_RX
PC1.GPIO_Label=D1_GREEN
PC1.Signal=GPIO_Output
PC10.Signal=SDIO_D2
PC11.Signal=SDIO_D3
PC12.Signal=SDIO_CK
PC14-OSC32_IN.Signal=RCC_OSC32_IN
PC15-OSC32_OUT.Signal=RCC_OSC32_OUT
PC2.GPIO_Label=D1_BLUE
PC2.Signal=GPIO_Output
PC3.GPIO_Label=D1_RED
PC3.Signal=GPIO_Output
PC8.Signal=SDIO_D0
PC9.Signal=SDIO_D1
PD2.Signal=SDIO_CMD
PH0-OSC_IN.Signal=RCC_OSC_IN
PH1-OSC_OUT.Signal=RCC_OSC_OUT

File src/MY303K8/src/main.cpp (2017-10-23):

/*******************************************************************************
 * Test unit for the development board: STM32F303K8Tx
 * *****************************************************************************
 * Copyright (C) 2016-2017 Mikhail Kulesh
 *
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
 * You should have received a copy of the GNU General Public License
 * along with this program.  If not, see <http://www.gnu.org/licenses/>.
 ******************************************************************************/

#include "StmPlusPlus/StmPlusPlus.h"

using namespace StmPlusPlus;

#define USART_DEBUG_MODULE "Main: "

class MyApplication : public Timer::EventHandler, RealTimeClock::EventHandler
{
private:

    UsartLogger log;

    RealTimeClock rtc;
    IOPin led1;
    IOPin led2;
    IOPin mco;
    Timer timer;

    volatile uint16_t counter;

    InterruptPriority irqPrioRtc;
    InterruptPriority irqPrioTimer;

public:

    MyApplication ():
        log(Usart::USART_1, IOPort::B, GPIO_PIN_6, GPIO_PIN_7, 115200),
        rtc(),
        led1(IOPort::B, GPIO_PIN_0, GPIO_MODE_OUTPUT_PP),
        led2(IOPort::B, GPIO_PIN_1, GPIO_MODE_OUTPUT_PP),
        mco(IOPort::A, GPIO_PIN_8, GPIO_MODE_AF_PP),
        timer(Timer::TIM_3, TIM3_IRQn),
        counter(0),
        irqPrioRtc(2, 0),
        irqPrioTimer(1, 0)
    {
        led1.putBit(true);
        led2.putBit(false);
        mco.activateClockOutput(RCC_MCO1SOURCE_PLLCLK, RCC_MCODIV_2);
    }

    virtual ~MyApplication ()
    {
        // empty
    }

    inline const Timer & getTimer () const
    {
        return timer;
    }

    inline RealTimeClock & getRtc ()
    {
        return rtc;
    }

    void run ()
    {
        log.initInstance();

        USART_DEBUG("Oscillator frequency: " << System::getExternalOscillatorFreq()
                    << ", MCU frequency: " << System::getMcuFreq());

        HAL_StatusTypeDef status = HAL_TIMEOUT;

        status = rtc.start(10*2000, RTC_WAKEUPCLOCK_RTCCLK_DIV2, irqPrioRtc, this);
        USART_DEBUG("RTC start status: " << status);

        status = timer.start(TIM_COUNTERMODE_UP, System::getMcuFreq()/2000 - 1,  1000);
        USART_DEBUG("Timer start status: " << status);
        timer.startInterrupt(irqPrioTimer, this);

        while (true)
        {
            // empty
        }
    }

    virtual void onTimerUpdate (const Timer *)
    {
        uint32_t sysTicks = HAL_GetTick() % 500;
        USART_DEBUG(counter << ": onTimerUpdate = " << sysTicks);
        led1.toggle();
        led2.toggle();
    }

    virtual void onRtcWakeUp ()
    {
        ++counter;
        timer.reset();
    }
};


MyApplication * appPtr = NULL;


int main(void)
{
    // Note: check the Value of the External oscillator mounted in PCB
    // and set this value in the file stm32f3xx_hal_conf.h

    HAL_Init();

    IOPort defaultPortA(IOPort::PortName::A, GPIO_MODE_INPUT, GPIO_PULLDOWN);
    IOPort defaultPortB(IOPort::PortName::B, GPIO_MODE_INPUT, GPIO_PULLDOWN);
    IOPort defaultPortC(IOPort::PortName::C, GPIO_MODE_INPUT, GPIO_PULLDOWN);

    // Set system frequency to 72MHz
    System::ClockDiv clkDiv;
    clkDiv.PLLM = RCC_HSE_PREDIV_DIV2;
    clkDiv.PLLN = RCC_PLL_MUL9;
    clkDiv.AHBCLKDivider = RCC_SYSCLK_DIV1;
    clkDiv.APB1CLKDivider = RCC_HCLK_DIV2;
    clkDiv.APB2CLKDivider = RCC_HCLK_DIV1;
    do
    {
        System::setClock(clkDiv, FLASH_LATENCY_2, System::RtcType::RTC_INT);
    }
    while (System::getMcuFreq() != 72000000L);

    MyApplication app;
    appPtr = &app;

    app.run();
}


extern "C" void SysTick_Handler(void)
{
    HAL_IncTick();
}

extern "C" void TIM3_IRQHandler()
{
    appPtr->getTimer().processInterrupt();
}

extern "C" void RTC_WKUP_IRQHandler()
{
    appPtr->getRtc().onSecondInterrupt();
}

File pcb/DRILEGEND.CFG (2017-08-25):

InputUserCfg = 1
SymbolLayer = 144
SymbolSize = 40
SymbolWidth = 4
TextSize = 70.0000
TextRatio = 5
IdxFnt = 0
decMM = 2
decMIL = 0
SortHoles = 1
TolPlated = 0.02
TolNonPlated = 0.03
PlatedStatusNot = NOT
PlatedStatusBoth = BOTH
PlatedStatusYes = YES
VerticalChart = 1
HighCellFactor = 1.10
WideCellFactor = 1.10
CellOutline = 4
TitleOutline = 4
TableOutline = 8
SymbTitle = Sym
ToolTitle = N°
MMTitle = MM
MilTitle = Mils
MicTitle = Mic
QtyTitle = Qty
TypeTitle = Plated
ToleTitle = Tol
SymbRank = 1
ToolRank = 2
MMRank = 4
MilRank = 3
MicRank = 0
QtyRank = 5
TypeRank = 6
ToleRank = 0
OutputDrillRack = 0
DrillRackFile = DRILLRACK.DRL
Unit = 0
OutputUserCfg = 1
UserCfgFile = DRILEGEND.CFG

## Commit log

2017-08-25 Added version 2 of the boards
    [lqfp_adapters.brd, lqfp_adapters.sch, stm_adapters.brd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]
2017-08-25 Added demo/test programs for the boards
    [MY303K8.cfg, MY303RB.cfg, MY373CB.cfg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]
2017-09-29 Early drop for STM32PiBoard
    [lqfp_adapters.brd, lqfp_adapters.sch, stm32_pi_board.brd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]
2017-10-01 Imprved stm32_pi_board
    [stm32_pi_board.brd, stm32_pi_board.sch]
2017-10-02 STM32-Pi Board submitted to factory
    [stm32_pi_board.brd]
2017-10-17 Added example for STM32-Pi Board
    [PI405RG-SWD.cfg]
2017-10-20 Fixed minor layout bugs
    [stm32_pi_board.brd, stm32_pi_board.sch]
2017-10-26 Updated PCB
    [stm32_pi_board.brd, stm32_pi_board.sch]
2017-11-09 Revision 1.1 submitted to factory
    [stm32_pi_board.brd, stm32_pi_board.sch]
2018-03-06 Implementes message containing pin state
2018-04-05 Added driver for audio DAC UDA1334
2018-05-03 Assembled board 1.2
    [stm32_pi_board.brd, stm32_pi_board.sch]
2018-05-07 Updated schematic
    [stm32_pi_board.sch]
2018-06-03 Minor code improvements
    [stm32_pi_board_bom.ods]
2018-06-06 Introduced Port and Pin in HardwareLayout
2018-06-08 Introduced DMA
2018-06-08 Introduced ADC
2018-06-11 Renamed Dma
2018-06-12 Reworked timers
2018-06-13 Introduced SPI
2018-06-14 Removed unused interrupts
2018-06-14 Improved Spi
2018-06-14 Spi using DMA
2018-06-21 Asynchron ADC
2018-06-22 Refactored DMA usage
2018-06-25 New version of pi_board
    [stm32_pi_board.brd, stm32_pi_board.sch]
2018-06-26 Added LMT86
    [stm32_pi_board.brd, stm32_pi_board.sch]
2018-06-27 Reworked class System
    [stm32_pi_board.sch]
2018-07-01 PCB revision 1.3
    [stm32_pi_board.brd, stm32_pi_board.sch]
2018-07-08 Revision 1.3 of Stm32-Pi-Board
    [stm32_pi_board.brd, stm32_pi_board.sch]
2018-07-27 Updated STM32 adapters
    [stm32_pi_board.brd, stm_adapters.brd, stm_adapters.sch]
2018-08-01 Submitted PiBoard v1.3
    [stm32_pi_board.brd, stm32_pi_board.sch]
2018-08-26 Updated BOM
    [stm32_pi_board.brd, stm32_pi_board.sch]
2021-04-05 moved cubeMX files
    [lqfp_adapters.brd]
2023-07-21 Added description
    [jtag-20-6.brd, jtag-20-6.sch, lqfp_adapters.brd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]

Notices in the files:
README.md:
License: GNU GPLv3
